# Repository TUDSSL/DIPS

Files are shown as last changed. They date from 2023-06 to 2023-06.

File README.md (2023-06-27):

# DIPS
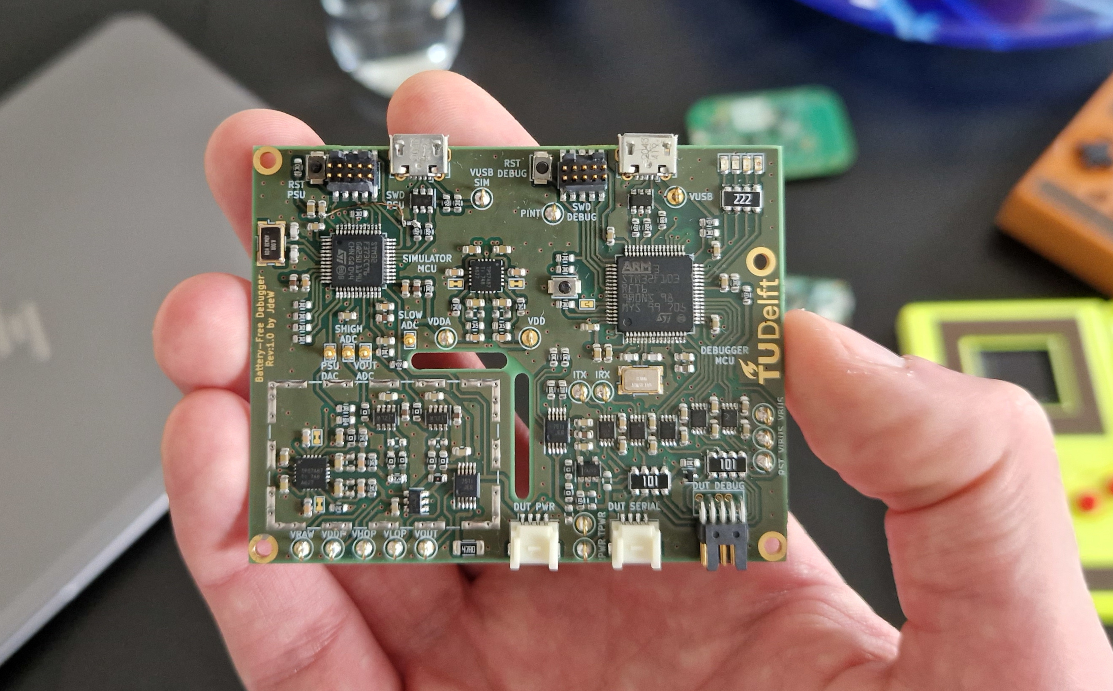
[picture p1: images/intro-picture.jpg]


This is the official public repository for **DIPS**: **D**ebugger for **I**ntermittently-**P**owered **S**ystems. The repository consists of all components that make DIPS:
- [Hardware](https://github.com/TUDSSL/DIPS/tree/master/hardware)
- [Debugger Firmware](https://github.com/TUDSSL/DIPS/tree/master/int-debugger-firmware)
- [Emulator Firmware](https://github.com/TUDSSL/DIPS/tree/master/int-debugger-emulator)
- [Emulator Host (GUI)](https://github.com/TUDSSL/DIPS/tree/master/int-debugger-emulator-host)
- [DIPS Console](https://github.com/TUDSSL/DIPS/tree/master/int-debugger-console)

## Project Overview
### Rationale
Intermittently-Powered or Battery-Free systems are low-powered embedded systems that experience frequent power failures. In recent years intermittently-powered systems have been explored excessively by the research community, but there was no good way of debugging these systems. DIPS aims to address this challenge. 

### Debugging Intermittently-Powered Systems
Common debuggers, like the [J-link](https://www.segger.com/products/debug-probes/j-link/), are perfect for debugging continuously-powered systems but will lose connection on a power failure when debugging intermittently-powered systems, making it useless for debugging battery-free systems. On top of that, intermittently-powered systems come with their own set of challenges by introducing new architectures like checkpointing. DIPS allows for continuous debugging despite power failures by reconnecting automatically and restoring the debugging state (Breakpoints) to the device under test. Scripts supplement the functionality of DIPS, allowing for automated tests of memory and peripheral consistency.

### Features:
DIPS integrates a fully featured emulator with close integration with an onboard hardware debugger. It can power devices under test through various modes and features current measurement capability. A key feature is the ability to pause emulation during debugger interaction, such as breakpoints. The emulator supports the following modes:
- Constant Voltage
- Sawtooth
- Square
- Triangle
- Virtual Buck-Boost (Allows for replaying energy harvesting traces to the device under test)
- Passive mode (Only takes over powering the device when prompted during debugging, requires passive debugging mode **mon passive_mode enable**)

The hardware debugger supports, through the associated console application, supports the following features:

- **energy_guards** energy-neutral code sections  where the emulator pauses
- **energy_breakpoints** that only trigger if the voltage is lower than the specified threshold
- **dips_mem_check** memory state consistency verification script, configured in **dips_testing.json**
- **dips_peripheral_check** peripheral state consistency verification script, configured in **dips_testing.json**
- Printing (**DIPS_PRINTF**), asserts (**DIPS_ASSERT**) and manually attaching (**DIPS_ATTACH**) through a simple C interface
- Passive operation (**wait_connect**) where the debugger only connects when prompted through a pin. 

### Hardware
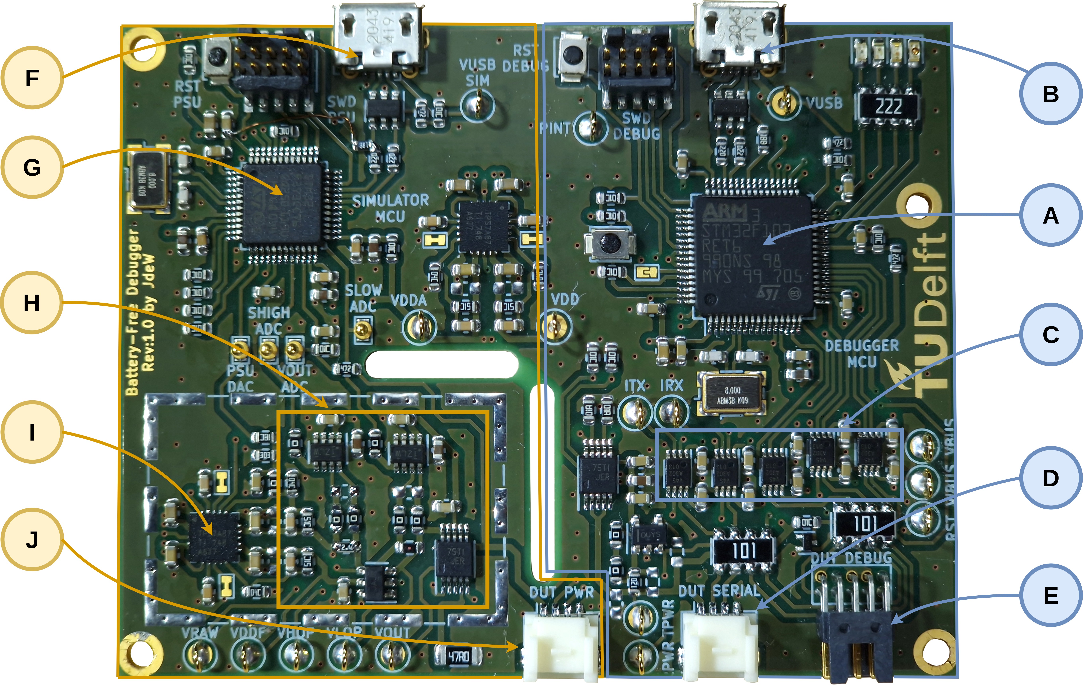
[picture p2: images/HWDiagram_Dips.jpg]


#### Hardware Debugger
The hardware design of the debugger centers around a STM32F103RET MCU (A) and is based on the [Black Magic Debug Probe](https://github.com/blackmagic-debug/blackmagic). It is able to communicate with the energy emulator through SPI. The MCU interfaces with the DUT through SWD/JTAG or SBW (E), I/O interrupt pins and acts as a UART-USB bridge (D). To translate the signals to the DUT voltage, first, the DUT voltage is buffered using a low input bias current buffer amplifier OPA192. Next, all the interfaces with the DUT are level shifted by level translators (C) using the buffered DUT
voltage. The debugger connects to the PC with USB (B). 

#### Energy Emulator 
Central to the energy emulator is the low-noise TPS7A87 (I) linear regulator. The regulator generates the adjustable supply rail to the DUT (J). Power consumption by the DUT is measured by two INA186 current sense amplifiers (H). The first amplifier with a 5.6 Ω sense resistor measures large currents without imposing a high burden voltage. The second amplifier with a 1000 Ω sense resistor measures low currents and is able to be bypassed at large currents preventing high burden voltages. Two analog switches allow for quickly disabling the output and discharging the output through a 47 Ω resistor. The emulator is controlled by a STM32F373 MCU (G). With its on-board DAC DIPS is able to adjust the linear regulator and samples the output voltage and the output of the current sense amplifiers (each using one of its dedicated on-board Sigma Delta ADCs). The energy emulator connects to the PC with USB (F)

#### Design files
In the **hardware** folder both the KICAD design files are provided together with a PDF schematic and gerbers.

## Getting Started
This repository has all information to build your own DIPS. Below we describe building and executing the complete repository of DIPS, including hardware, debugger software, emulator software and both emulator and console applications.

### Building the Debugger Firmware
The hardware debugger firmware is based on the [Black Magic Probe](https://github.com/blackmagic-debug/blackmagic) and can be found in the [/int-debugger-firmware](https://github.com/TUDSSL/DIPS/tree/master/int-debugger-firmware) folder

#### Build Process
After cloning the repository one can compile the firmware in two ways, first is by running it as a [PlatformIO](https://platformio.org/) project or by building it from scratch using the provided cmake files running the following section:

```
$ cd int-debugger-firmware
$ pio run
```

After building, you can upload the firmware to the MCU using your favourite flashing method whilst powering the platform using USB.

#### Last Tested Software Versions
This software was build successfully with these software versions:

- CMake version 3.26.3 
- arm-none-eabi-gcc version 13.1.0 
- arm-none-eabi-newlib version 4.3.0.20230120
- arm-none-eabi-binutils version 2.40 
- PlatformIO version 6.1.7

### The Emulator Firmware
The emulator firmware is located in the [/int-debugger-emulator](https://github.com/TUDSSL/DIPS/tree/master/int-debugger-emulator) folder

#### Build Process
After cloning the repository the emulator can be compiled and build by running the enclosed cmake commands:

```
$ cd int-debugger-emulator
$ mkdir build
$ cd build
$ cmake ..
$ make
```

After building, you can upload the firmware to the MCU using your favourite flashing method whilst powering the platform using USB.

#### Note on the Emulator Firmware
The firmware is based upon the [FreeRTOS](https://www.freertos.org/) framework, allowing real-time switching of tasks required for the emulator.

#### Last Tested Software Versions
This software was build successfully with these software versions:

- CMake version 3.26.3 
- arm-none-eabi-gcc version 13.1.0 
- arm-none-eabi-newlib version 4.3.0.20230120
- arm-none-eabi-binutils version 2.40
- Protobuf version 21.12

### Building the Emulator Host Software
The next part of software runs on the host PC and is used for communicating with the hardware emulator. The sofware can be found in the [/int-debugger-emulator-host](https://github.com/TUDSSL/DIPS/tree/master/int-debugger-emulator-host) folder.

#### Build Process
After cloning the repository the emulator host application can be compiled and build by running the following commands:

```
$ cd int-debugger-emulator-host
$ cmake .
$ make
```

#### Last Tested Software Versions
This software was build successfully with these software versions:

- [QT](https://www.qt.io/) version 5.15.9
- [HighFive](https://github.com/BlueBrain/HighFive) commit 00dad7172c
- Protobuf version 21.12
- HDF5 version 1.14.1

### The DIPS Console Software
The next part of software also runs on the host PC and is used as a GDB wrapper, allowing the added features of DIPS. The sofware can be found in the [/int-debugger-console](https://github.com/TUDSSL/DIPS/tree/master/int-debugger-console) folder.

#### Setup
Since the DIPS console is a python executable, there is no need for compilation. Install the python libraries mentioned in the `requirements.txt` file and you should be good to go.

#### Last Tested Software Versions
This software was build successfully with these software versions:

- Python version 3.11.3
- Python-pyGDBmi version 0.11.0.0
- Python-pyserial version 3.5
- Python-prompt_toolkit version 3.0.38 
- Python-cmsis_svd version 0.4

#### Execute DIPS Console Application
The DIPS console application can be started by calling the `python3 main.py`, if you have an elf-file binary, you can load this by adding this as extra parameter `python3 main.py firmware.elf`. Other GDB parameters and queries from the command line are avaliable as well.

##### Connecting to DIPS
If you have your DIPS connected over USB you can connect to the hardware by running the `connect` command. The console will automatically search for a DIPS serial connection, establish this connection and connect to the attached device under test. Now one can start debugging intermittenlty-powered systems with DIPS, just like debugging regular powered embedded systems. Manual connection to DIPS is also possible by running the following sequence:

```
(gdb) tar ext /dev/ttyACM0
(gdb) mon s
(gdb) attach 1
```

##### Sample session
After connecting to the DIPS and the device under test, regular arm-none-eabi-gdb commands are availble for use:

```
> python3 main.py example.elf
...<GDB Copyright message>
(gdb) connect
Remote debugging using /dev/ttyACM0
Target voltage: 3.00V
Available Targets:
No. Att Driver
 1      STM32F40x M3/M4
Attaching to program: <code_folder>/example.elf, Remote target
0x800007c in main ()
(gdb) load
Loading section .text, size 0x5868 lma 0x8000000
Loading section .data, size 0x9e0 lma 0x8005868
Loading section .rodata, size 0x254 lma 0x8006248
Start address 0x800007c, load size 25756
Transfer rate: 31 KB/sec, 919 bytes/write.
(gdb) b main
(gdb) c
Breakpoint 1 at 0x80000e8: file <code_folder>/main.c, line 20.
(gdb)
```
## How to Cite This Work

The results of this project have been published in a peer-reviewed academic publication (from which all technical figures in this file originate). Details of the publication are as follows.

* **Authors and the project team:** [Jasper de Winkel](https://www.jasperdewinkel.com/), [Tom Hoefnagel](https://www.linkedin.com/in/tobrec), [Boris Blokland](https://www.linkedin.com/in/boris-blokland-2a0b22138/), [Przemysław Pawełczak](https://www.pawelczak.net/)
* **Publication title:** _DIPS: Debug Intermittently-Powered Systems Like Any Embedded System_
* **Pulication venue:** [Proceedings of ACM SenSys 2022](http://sensys.acm.org/2022/)
* [**Link to publication**](https://doi.org/10.1145/3560905.3568543)

To cite this publication please use the following BiBTeX entry.

```
@inproceedings{dewinkel:sensys:2022:dips,
 author = {de Winkel, Jasper and Hoefnagel, Tom and Blokland, Boris and Pawe\l{}czak, Przemys\l{}aw},
 title = {{DIPS}: Debug Intermittently-Powered Systems Like Any Embedded System},
 booktitle = {Proc. SenSys},
 year = {2022},
 address = {Boston, MA, USA},
 date = nov # " 6--9",
 publisher = {ACM},
 url = {https://doi.org/10.1145/3560905.3568543}
}
```

## Acknowledgments

This research project was supported by [Netherlands Organisation for Scientific Research](https://www.nwo.nl/en), partly funded by the [Dutch Ministry of Economic Affairs and Climate Policy](https://www.government.nl/ministries/ministry-of-economic-affairs-and-climate-policy), through [TTW Perspective program ZERO (P15-01)](https://www.nwo.nl/en/researchprogrammes/perspectief/previous-awards/zero-towards-energy-autonomous-systems-iot) within Project P1.

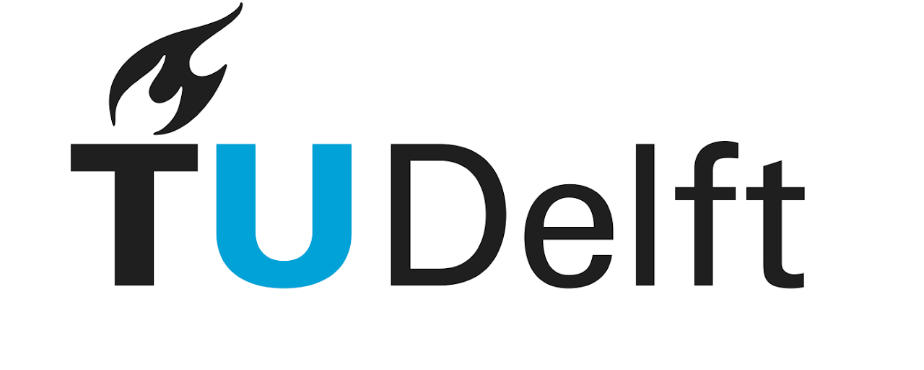
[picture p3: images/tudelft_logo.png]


## Copyright

Copyright (C) 2022 TU Delft Embedded Systems Group/Sustainable Systems Laboratory.

MIT Licence or otherwise specified. See [license](https://github.com/TUDSSL/ENGAGE/blob/master/LICENSE) file for details.

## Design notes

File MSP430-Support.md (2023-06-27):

# DIPS Support for MSP430
In this document we outline the current development status of supporting [MSP430 MCUs](https://www.ti.com/microcontrollers-mcus-processors/microcontrollers/msp430-microcontrollers/overview.html) with DIPS. As at the base of DIPS' debugging features is [Black Magic software](https://github.com/blackmagic-debug), where MSP430 support is not provided per default, thus needs to be manually added. DIPS does support the [MSP432 MCU](https://en.wikipedia.org/wiki/TI_MSP432) series (as this is an ARM core), and generic support is provided for Cortex-M0/M3 and M4. Any chip with these ARM cores should be debuggable using DIPS, even though they are not directly supported. Additional features, such as programming, would require device-specific implementation in DIPS/Black Magic as these implementations vary per chip unfortunately.

First, we outline the interface and how the DIPS debugger connects to the MSP430 under test. Second, we further describe the software support.

_Important note_: Since the MSP430 debug feature is under active development, this document will be updated as further support is added.

## Interface
For MSP430 devices the Spy-by-wire (SBW) interface is commonly used within intermittent computing platforms. This is a serialized JTAG interface custom to the Texas Instruments (TI) MSP430 platform reducing the number of required pins during debugging. 

On development boards of the MSP430, such as [MSP-EXP430FR5994](https://www.ti.com/product/MSP430FR5994) and [MSP-EXP430FR5969](https://www.ti.com/product/MSP430FR5969), communication with the onboard debugger occurs through SBW. As this is the most common option for debugging (and intermittent systems are most often bound by space restriction), we chose to support MSP430 through SBW. Using an adapter cable, we can directly connect MSP430 devices to DIPS. The connections of this cable are listed in the figure below. We note that these connections are in addition to a possible connection to the emulator through the emulator output connector on DIPS.

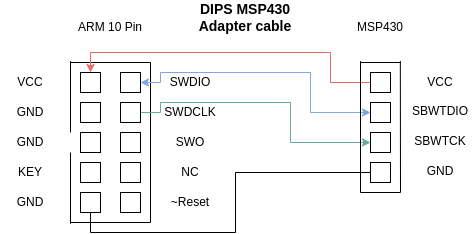
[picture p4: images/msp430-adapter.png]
DIPS MSP430 Adapter Cable


Since DIPS's architecture includes level shifters on the debugger output, SBW signals generated from the debugger are shifted to the voltage sensed on the VCC pin of the MSP430, fulfilling the required signal level constraints. Therefore we do not foresee any issues regarding the hardware capability of DIPS debugging MSP430 since the level shifters of DIPS are capable of 60 Mbps transfer at 1.5 V, far exceeding the connection requirements. The MCU controlling the debugging within DIPS is also far more capable than the chips serving as integrated debuggers in the TI development kits. Hence the timing requirements of DIPS should be met without issue.

## Spy-by-Wire Protocol
TI provides a user's guide for [programming with the JTAG/SBW interface](https://www.ti.com/lit/ug/slau320aj/slau320aj.pdf). Our implementation is based on the protocol description in this document. Please note however that this document does not provide information about setting breakpoints and watchpoints. This unfortunately requires reverse engineering of the open source [debugger code](https://www.ti.com/tool/MSPDS) from TI.

For the record, the figure below (taken from [TI Users guide (Figure 2-10)](https://www.ti.com/lit/ug/slau320aj/slau320aj.pdf)) shows a detailed diagram of how SBW operates.

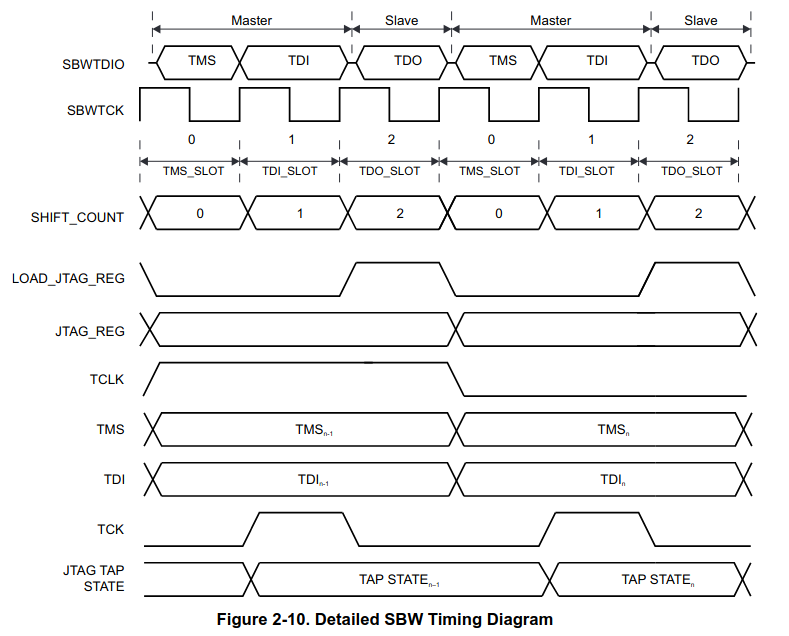
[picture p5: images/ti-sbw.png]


The traditional JTAG signals TMS, TDI and TDO are multiplexed on a single I/O line. This introduces further timing requirements in order to keep alignment with the MSP430 under test. As of now the SBW communication primitives are implemented and further features are developed, such as CPU control and reading/writing from/to memory.

## DIPS Software Support

| Command | Status |
| --- | --- |
| Attach/detatch | Yes |
| Register reads/writes | Yes | 
| Reset | Pending | 
| Halt/resume | Yes | 
| Breakpoints | Yes | 
| Watchpoints | Pending | 
| Energy breakpoints | Yes | 
| Energy guards | Yes | 

### Attaching

DIPS queries the JTAG and SWD interfaces to connect with devices under test. When a device responds, the target ID is retrieved together with vendor-specific IDs (when possible) to determine FLASH/RAM sizes etc. Then the correct target driver is loaded.

We extend this interface with another query to find MSP430 devices on the SBW bus. When an MSP430 device responds to the query, the internal commands (e.g. reg read/write/ breakpoints) are switched to custom MSP430 compatible ones, retargeting the debugger from ARM to MSP430. 

Below a screenshot is shown of DIPS attaching to an MSP430 from the console perspective. In addition, some of the underlying SBW queries between DIPS and the MSP430 are shown to fetch the COREID and JTAGID to identify the chip.

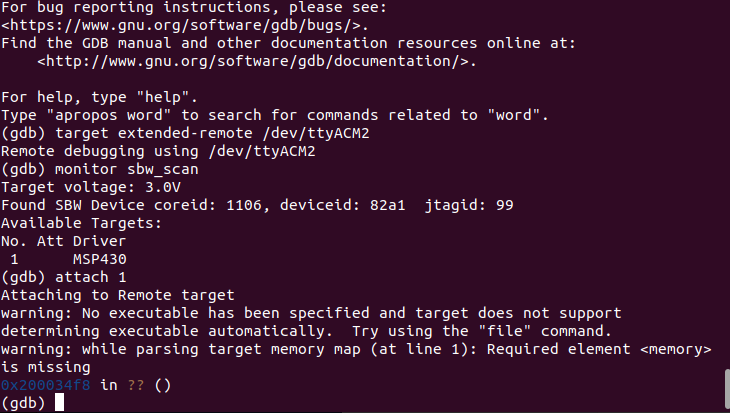
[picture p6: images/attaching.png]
DIPS Attach in console

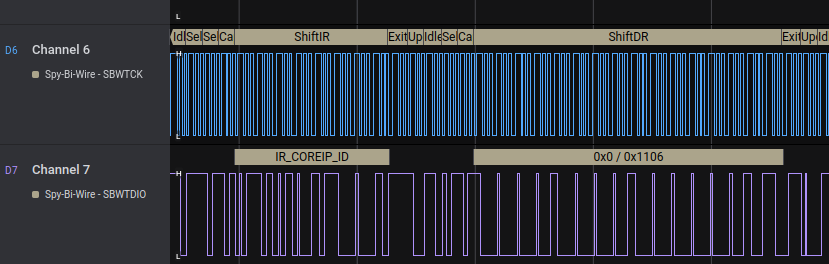
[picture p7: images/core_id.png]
Trace COREID read

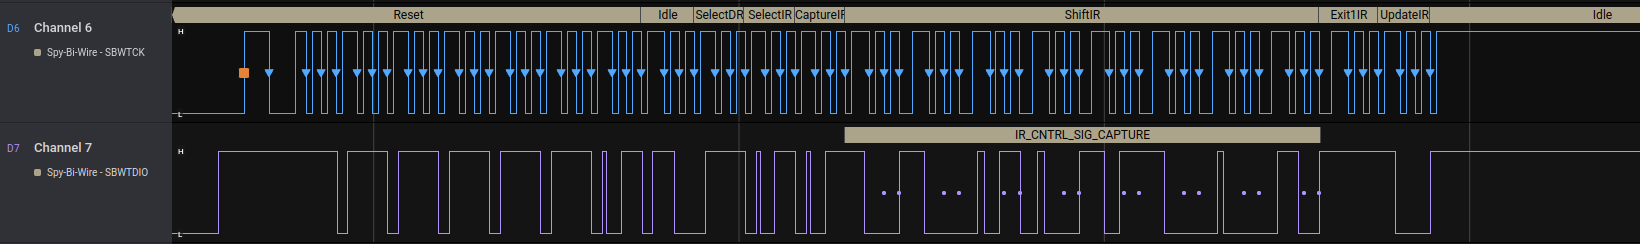
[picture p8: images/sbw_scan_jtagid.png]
Trace JTAGID


## Debugging MSP430 with DIPS

Due to the different instruction set of the MSP430, TI has its own fork of the GCC suite, named MSP430-GCC. TI's development environment for MSP430 is named Code Composer Studio (CCS), an Eclipse-based IDE. Per default this IDE uses TI's proprietary debugging engine connecting to the MSP-FET debugger. When debugging using open source tools, a common method is to use msp430-gdb and a translation library like MSPDebug to act as a GDB server converting gdb client commands to the TI interface that controls the MSP-FET.

We propose a setup similar to the ARM debugging scenario where DIPS directly acts as the GDB Server and then internally converts messages to SBW commands. We note that even in the case of using CCS open-source suite, debugging with GDB can be configured. An overview of these options is shown in the figure below.

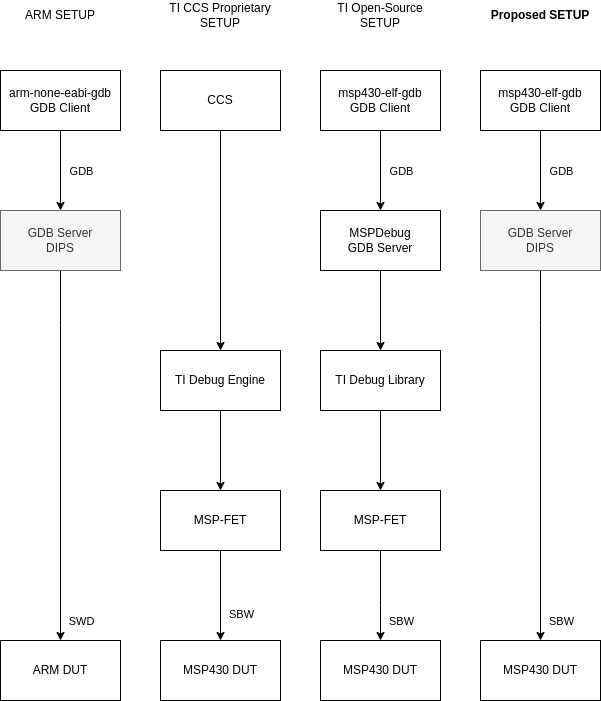
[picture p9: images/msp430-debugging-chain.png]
DIPS MSP430 Debugging Architecture


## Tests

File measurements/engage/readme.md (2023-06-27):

For this example we used an unmodified version of the Battery-free Game Boy source code from (https://github.com/TUDSSL/ENGAGE)

From the ENGAGE folder:

```
cd software/build/
cmake ../
make -j12
```

The emulator binary was then flashed to ENGAGE and a game was loaded prior to starting the measurements. Logs and settings of the ENGAGE measurements can be found in their respective folders.

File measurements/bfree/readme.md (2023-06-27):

In order to run the BFree measurements, BFree has to be modified to allow access to SWD. Per default the SWD pins are used as GPIO, in both Micropython as the bootloader. 

Both a modified version of BFree and the bootloader is provided in the software folder. Logs and settings of the BFree measurements can be found in their respective folders.

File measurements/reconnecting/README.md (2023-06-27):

# Reconnecting Measurement Artefacts
Here you can find the raw measurements preformed for section 5.1 - Figure 4. 
Using the [Saleae Logic Pro 8](http://downloads.saleae.com/specs/Logic+Pro+8+Product+Fact+Sheet.pdf)

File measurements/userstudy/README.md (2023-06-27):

# Userstudy Artefacts

Create the plot using the plotter.py. 
Please note in study2 are unfinished results. These results can be ignored as this was due to a bug in the suvey environment.

## Requirements
Pyton 3
Numpy
Matplotlib

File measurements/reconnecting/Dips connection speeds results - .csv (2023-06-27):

MCU | NRF52 |  | ATMEL |  | Apollo 3 |  | STM32 |  | NXP
#1 | 297.9 | 57.8 | 314 | 87.4 | 280 | 105 | 302.8 | 77.5 | 304.3 | 152.2
#2 | 267.2 | 91.12 | 317 | 79.8 | 303.6 | 102.5 | 340.4 | 87.9 | 306.1 | 115
#3 | 296 | 106.1 | 287.6 | 69.75 | 431.4 | 123.9 | 302.1 | 95.6 | 271.6 | 98.7
#4 | 288.6 | 65 | 327.4 | 66.52 | 318.4 | 87.8 | 295.6 | 111.4 | 277.5 | 66.8
#5 | 296.3 | 119.1 | 328 | 93.9 | 337.1 | 94.8 | 320.7 | 67.4 | 333.2 | 142
#6 | 285.1 | 68.6 | 438.4 | 45 | 339.9 | 105 | 331.8 | 100.7 | 308.3 | 139.5
#7 | 341.3 | 29 | 281.8 | 93.1 | 313.5 | 57 | 327.9 | 62.1 | 341.7 | 91.7
#8 | 345.2 | 73 | 304.9 | 72.2 | 332.9 | 81 | 258.3 | 33 | 326.6 | 65.6
#9 | 353.1 | 52 | 308.6 | 60.8 | 351.1 | 80.9 | 351.8 | 22.5 | 340.2 | 91.7
#10 | 340.4 | 65 | 338.9 | 89.2 | 302.8 | 118.3 | 354.9 | 23.4 | 286.1 | 94.4
Average | 311.11 | 72.672 | 324.66 | 75.767 | 331.07 | 95.62 | 318.63 | 68.15 | 309.56 | 105.76

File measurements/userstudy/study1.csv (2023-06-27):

id. Response ID | submitdate. Date submitted | lastpage. Last page | startlanguage. Start language | seed. Seed | Introduction. Ready? | IntroductionB. Ready? | A000. Enter the password to continue (Ask US after Playing with the debugger for 15 minutes) | BugA10. Bug 1: This first bug has to do with how the Fibonacci is defined here. This Fibonacci function uses n+1 and n+2 what leads to a diverging function as the base case is never reached. The solution is to replace n+1 by n-1 and n+2 by n-2. Did you find the bug? | BugA11[SQ001]. How difficult was it to find the bug? [Debugger] | BugA12. Did you find the bug using the debugger? (Otherwise please specify) | BugA12[other]. Did you find the bug using the debugger? (Otherwise please specify) [Other] | BugA13[SQ001]. Did the debugger help in finding the bug? [Debugger] | BugA20. Bug 2: The second bug can be found in the matrix multiply function (tasks/matrix.cpp). Here the sum variable is cleared only every row iteration, while it should be cleared every column as well. The solution is to move the int sum =0 to within the (j &lt; 6) while loop. Did you find the bug? | BugA21[SQ001]. How difficult was it to find the bug? [Debugger] | BugA22. Did you find the bug using the debugger? (Otherwise please specify) | BugA22[other]. Did you find the bug using the debugger? (Otherwise please specify) [Other] | BugA23[SQ001]. Did the debugger help in finding the bug? [Debugger] | BugA30. Bug 3: The last bug is a famous intermittent bug. The UART peripheral is only initialized after the restoration of the memory after a power failure. This means whenever a power failure occurs and case 2 or 3 is true, this UART initialization is skipped. One can solve this by moving the UART setup to someplace before the switch-case. Did you find the bug? | BugA31[SQ001]. How difficult was it to find the bug? [Debugger] | BugA32. Did you find the bug using the debugger? (Otherwise please specify) | BugA32[other]. Did you find the bug using the debugger? (Otherwise please specify) [Other] | BugA33[SQ001]. Did the debugger help in finding the bug? [Debugger] | B000. Enter the password to continue (Ask US after Playing with the debugger for 15 minutes) | BugB10. Bug 1: The snippet shows the first bug of the WISP system. The blink_COUNTER variable is misspelt, this creates an infinite loop as blink_C0UNTER is never updated. The solution is to replace the 0 with O. Did you find the bug? | BugB11[SQ001]. How difficult was it to find the bug? [Debugger] | BugB12. Did you find the bug using the debugger? (Otherwise please specify) | BugB12[other]. Did you find the bug using the debugger? (Otherwise please specify) [Other] | BugB13[SQ001]. Did the debugger help in finding the bug? [Debugger] | BugB20. Bug 2: The second bug has to do with the result variable, which is never pointed to any memory. This can be solved by allocating the memory using malloc or by initializing the array at the beginning. Did you find the bug? | BugB21[SQ001]. How difficult was it to find the bug? [Debugger] | BugB22. Did you find the bug using the debugger? (Otherwise please specify) | BugB22[other]. Did you find the bug using the debugger? (Otherwise please specify) [Other] | BugB23[SQ001]. Did the debugger help in finding the bug? [Debugger] | BugB30. Bug 3: The snippet shows bug 3. The initialization of the ADC (setup_adc()) happens after the restoration, although, if restoring after a power failure case 2 or 3 is true, the setup is not executed. This is a very common mistake in Intermittent Computing Systems. The solution is to move the setup_adc() function above the restoration (switch case) Did you find the bug? | BugB31[SQ001]. How difficult was it to find the bug? [Debugger] | BugB32. Did you find the bug using the debugger? (Otherwise please specify) | BugB32[other]. Did you find the bug using the debugger? (Otherwise please specify) [Other] | BugB33[SQ001]. Did the debugger help in finding the bug? [Debugger] | C1[SQ001]. If you would work on the code for battery-free device: would you use this debugger system? [System A] | C1[SQ002]. If you would work on the code for battery-free device: would you use this debugger system? [System B] | C2[SQ001]. Was the debugging experience with each debugging system close to the one you have? [System A] | C2[SQ002]. Was the debugging experience with each debugging system close to the one you have? [System B] | C3[SQ001]. How intuitive to use was each of the debugging systems? [System A] | C3[SQ002]. How intuitive to use was each of the debugging systems? [System B] | C4[SQ001]. How easy to use was each of the debugging systems? [System A] | C4[SQ002]. How easy to use was each of the debugging systems? [System B] | C5. What are the positive aspects about System B? | C6. What are the negative aspects about System B? | C7. What are the positive aspects about System A? | C8. What are the negative aspects about System A? | A12. What is your age? | A1. You are: | A2. With which programming language you are most comfortable with? | A2[other]. With which programming language you are most comfortable with? [Other] | A3. Have you ever used an Integrated Development Environment (IDE) when developing your applications? | A4. Do you prefer to develop your applications using an Integrated Development Environment (IDE)? | A5[SQ001]. How do you assess your embedded systems programming skills? [Expertise] | A6. Have you ever used hardware-based debuggers for your embedded project (such as Seggers J-link - see photo below)? | A7. Have you ever used debugging techniques such as breakpoints, watchpoints, memory views, peripheral views, etc. while debugging an embedded system?
4 | 1980-01-01 00:00:00 | 6 | en | 1653865737 | Yes | Yes | apple | No |  |  |  |  | No |  |  |  |  | No |  |  |  |  | pear | No |  |  |  |  | No |  |  |  |  | No |  |  |  |  | Yes | No | Similar to what I am used to | Different from what I am used to | Intuitive | Non-intuitive | Neither easy nor difficult | Neither easy nor difficult | I think this system might be to the liking of those who prefer terminal over GUI. | Not very intuitive and probably unlike what most users are used to. | Very similar to most debuggers. People will have an easier time learning how to use this one. | Can't think of any. | 23 | Female | Python |  | Yes | Yes | Some experience | No | Yes
5 | 1980-01-01 00:00:00 | 6 | en | 219549667 | Yes | Yes | apple | No |  |  |  |  | No |  |  |  |  | No |  |  |  |  | pear | No |  |  |  |  | No |  |  |  |  | No |  |  |  |  | No | Yes | Similar to what I am used to | Similar to what I am used to | Intuitive | Non-intuitive | Somewhat difficult | Somewhat difficult | It allows you to set breakpoints in the code. Also, the terminal debugger may allow for automated scripts, and result reporting. | Having to reflash after setting a new breakpoint in the code. | Being able to use the GUI debugging buttons (step over, step out, etc.) which is what I'm used to. | The program got a segmentation fault at the start, and the debugger output could not point me in the right direction. | 24 | Male | C/C++ |  | Yes | Yes | Little experience | Yes | Yes
6 | 1980-01-01 00:00:00 | 6 | en | 1705827728 | Yes | Yes | apple | Yes | Neither easy nor difficult | Yes |  | Yes | No |  |  |  |  | No |  |  |  |  | pear | No |  |  |  |  | No |  |  |  |  | No |  |  |  |  | Yes | Yes | Different from what I am used to | Different from what I am used to | Intuitive | Non-intuitive | Neither easy nor difficult | Neither easy nor difficult | terminal driven (less switching once learning it) | terminal driven (steep learning curve) | tightly integrated to IDE | switching between tabs for building/loading | 34 | Male | Python |  | Yes | Yes | A lot of experience | Yes | Yes
7 | 1980-01-01 00:00:00 | 6 | en | 15004810 | Yes | Yes | apple | Yes | Neither easy nor difficult | Yes |  | Some What | No |  |  |  |  | No |  |  |  |  | pear | No |  |  |  |  | No |  |  |  |  | No |  |  |  |  | Yes | Yes | Similar to what I am used to | Different from what I am used to | Neither intuitive nor non-intuitive | Non-intuitive | Easy | Somewhat difficult | It shows the voltage stored in the capacitor if you're careful with the temporary stored energy such that it has not too little or too much voltage. | I was struggling with errors that occur when using debug commands, therefore rendering me to be unable to even start finding the bugs. | It was easy and intuitive to work with. | The green restart button doesn't seem to function correctly. Had to go through some pop-up windows. | 23 | Male | C/C++ |  | Yes | Yes | A lot of experience | Yes | Yes
8 | 1980-01-01 00:00:00 | 6 | en | 1264031530 | Yes | Yes | apple | Yes | Neither easy nor difficult | Yes |  | Yes | No |  |  |  |  | No |  |  |  |  | pear | No |  |  |  |  | No |  |  |  |  | No |  |  |  |  | Yes | No | Similar to what I am used to | Similar to what I am used to | Absolutely intuitive | Absolutely intuitive | Easy | Somewhat difficult | programmer friendly | need proper documentation before we can work on it. | Easy to use. similar to other debuggers | none | 26 | Male | Python |  | Yes | Yes | Some experience | Yes | Yes
9 | 1980-01-01 00:00:00 | 6 | en | 1750218359 | Yes | Yes | apple | Yes | Easy | Yes |  | Yes | No |  |  |  |  | No |  |  |  |  | pear | No |  |  |  |  | No |  |  |  |  | No |  |  |  |  | Yes | No | Similar to what I am used to | Similar to what I am used to | Intuitive | Non-intuitive | Easy | Somewhat difficult | I am used to GDB debugger for C/C++ debugging, so it was bit similiar to that. | Adding breakpoints in the code and compiling again is cumbersome to do everytime. 'wait, int, break' commands is not so initutive. | Compiling once is enough to debug in the hardware. Reflashing is not required. Breakpoints and continuing into the code is more of GUI based and intuituve than browsing through the code. | Had a bit of learning or getting used time, but once got a hang of it, it was slick and easy. | 27 | Male | C/C++ |  | Yes | Yes | A lot of experience | No | Yes
10 | 1980-01-01 00:00:00 | 6 | en | 1441815904 | Yes | Yes | apple | Yes | Neither easy nor difficult | Yes |  | Yes | No |  |  |  |  | No |  |  |  |  | pear | No |  |  |  |  | No |  |  |  |  | No |  |  |  |  | No | No | Very different from what I am used to | Different from what I am used to | Intuitive | Non-intuitive | Somewhat difficult | Very difficult | None, I still have no clue what it is. | Debugger does not work as described. No resolving of symbols. | Nice to set breakpoints in editor. | Still don't understand how to use it. | 44 | Male | C/C++ |  | Yes | No | A lot of experience | Yes | Yes
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

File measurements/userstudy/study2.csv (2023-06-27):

Response ID,Date submitted,Last page,Start language,Seed,Ready?,Ready?,Enter the password to continue (Ask US after Playing with the debugger for 15 minutes),Bug 1:     This first bug has to do with how the Fibonacci is defined here. This Fibonacci function uses n+1 and n+2 what leads to a diverging function as the base case is never reached. The solution is to replace n+1 by n-1 and n+2 by n-2.       Did you find the bug?    ,How difficult was it to find the bug? [Debugger],Did you find the bug using the debugger? (Otherwise please specify),Did you find the bug using the debugger? (Otherwise please specify) [Other],Did the debugger help in finding the bug? [Debugger],"Bug 2:     The second bug can be found in the matrix multiply function (tasks/matrix.cpp). Here the sum variable is cleared only every row iteration, while it should be cleared every column as well. The solution is to move the int sum =0 to within the (j &lt; 6) while loop.       Did you find the bug?    ",How difficult was it to find the bug? [Debugger],Did you find the bug using the debugger? (Otherwise please specify),Did you find the bug using the debugger? (Otherwise please specify) [Other],Did the debugger help in finding the bug? [Debugger],"Bug 3:     The last bug is a famous intermittent bug. The UART peripheral is only initialized after the restoration of the memory after a power failure. This means whenever a power failure occurs and case 2 or 3 is true, this UART initialization is skipped. One can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
1,,2,en,704032007,Yes,Yes,,N/A,,,,,N/A,,,,,N/A,,,,,,N/A,,,,,N/A,,,,,N/A,,,,,,,,,,,,,,,,,,N/A,,,N/A,N/A,,N/A,N/A,N/A,N/A,N/A,N/A,,N/A,N/A,,,,,,,,,,,,,,,,,,,,,,,,,,,,,,,,,,,,,,,,,,,,,,,,,,,,,,,,
2,,2,en,54428909,Yes,Yes,,N/A,,,,,N/A,,,,,N/A,,,,,,N/A,,,,,N/A,,,,,N/A,,,,,,,,,,,,,,,,,,N/A,,,N/A,N/A,,N/A,N/A,N/A,N/A,N/A,N/A,,N/A,N/A,,,,,,,,,,,,,,,,,,,,,,,,,,,,,,,,,,,,,,,,,,,,,,,,,,,,,,,,
3,,2,en,948952438,Yes,Yes,pear,N/A,,,,,N/A,,,,,N/A,,,,,,N/A,,,,,N/A,,,,,N/A,,,,,,,,,,,,,,,,,,N/A,,,N/A,N/A,,N/A,N/A,N/A,N/A,N/A,N/A,,N/A,N/A,,,,,,,,,,,,,,,,,,,,,,,,,,,,,,,,,,,,,,,,,,,,,,,,,,,,,,,,
4,2022-09-26 12:23:05,6,en,1899562523,Yes,Yes,apple,Yes,Somewhat difficult,Yes,,A little,Yes,Very difficult,Other,the logic of summation,No,No,,,,,pear,No,,,,,Yes,Somewhat difficult,Other,logic and experience with c,No,No,,,,,Yes,No,Similar to what I am used to,Similar to what I am used to,Intuitive,Non-intuitive,Somewhat difficult,Very difficult,"With some more experience, i could imagine that you have more control over the way this debugger works.",it is counterintuitive. the need for flushing especially.,intuitive and commonly used,a bit of a black box what is actually happening,28,Male,Python,,Yes,No,Little experience,No,Yes,Yes,Yes,Yes,No,,No,No,Somewhat difficult,,,,,,,,,,,,,,,,,,,,,,,,,,,,,,,,,,,,,,,,,,,,,,,,,,,,,,,
5,,2,en,241951371,Yes,Yes,,N/A,,,,,N/A,,,,,N/A,,,,,,N/A,,,,,N/A,,,,,N/A,,,,,,,,,,,,,,,,,,N/A,,,N/A,N/A,,N/A,N/A,N/A,N/A,N/A,N/A,,N/A,N/A,,,,,,,,,,,,,,,,,,,,,,,,,,,,,,,,,,,,,,,,,,,,,,,,,,,,,,,,
6,,3,en,511071445,Yes,Yes,apple,Yes,Easy,Yes,,Yes,Yes,Neither easy nor difficult,Yes,,Yes,No,,,,,,N/A,,,,,N/A,,,,,N/A,,,,,,,,,,,,,,,,,,N/A,,,N/A,N/A,,N/A,N/A,N/A,N/A,N/A,N/A,,N/A,N/A,,,,,,,,,,,,,,,,,,,,,,,,,,,,,,,,,,,,,,,,,,,,,,,,,,,,,,,,
7,2022-09-26 14:27:16,6,en,1750703097,Yes,Yes,apple,Yes,Easy,Yes,,Yes,Yes,Neither easy nor difficult,Yes,,Yes,No,,,,,pear,Yes,Very difficult,Yes,,A little,No,,,,,No,,,,,Yes,No,Similar to what I am used to,Very different from what I am used to,Absolutely intuitive,Absolutely non-intuitive,Very easy,Very difficult,I suppose having the breakpoints directly in the source files makes it easier to have the same breakpoints on multiple machines,"- Recompiling after every change in breakpoints is very cumbersome
- Being ""CLI only"" makes it hard to make intuitive sense of what is happening
-  I wasn't able to define multiple breakpoints","- Easy to use and understand
- Changing breakpoint locations on the go is helpful
- Stepping through code is very useful
- Having all the values of variables in the context in one overview is nice",Compared to system B I cannot think of any,27,Male,C/C++,,Yes,Yes,A lot of experience,Yes,Yes,Yes,Yes,Yes,Yes,,No,No,Somewhat difficult,,,,,,,,,,,,,,,,,,,,,,,,,,,,,,,,,,,,,,,,,,,,,,,,,,,,,,,
8,,3,en,647297054,Yes,Yes,apple,No,,,,,No,,,,,No,,,,,,N/A,,,,,N/A,,,,,N/A,,,,,,,,,,,,,,,,,,N/A,,,N/A,N/A,,N/A,N/A,N/A,N/A,N/A,N/A,,N/A,N/A,,,,,,,,,,,,,,,,,,,,,,,,,,,,,,,,,,,,,,,,,,,,,,,,,,,,,,,,
9,,2,en,694785966,Yes,Yes,,N/A,,,,,N/A,,,,,N/A,,,,,,N/A,,,,,N/A,,,,,N/A,,,,,,,,,,,,,,,,,,N/A,,,N/A,N/A,,N/A,N/A,N/A,N/A,N/A,N/A,,N/A,N/A,,,,,,,,,,,,,,,,,,,,,,,,,,,,,,,,,,,,,,,,,,,,,,,,,,,,,,,,
10,2022-09-27 12:29:22,6,en,37717934,Yes,Yes,apple,Yes,Easy,Yes,,A little,No,,,,,No,,,,,pear,Yes,Somewhat difficult,Yes,,A little,No,,,,,No,,,,,Yes,No,Similar to what I am used to,Neither different nor similar,Non-intuitive,Non-intuitive,Neither easy nor difficult,Very difficult,You can work faster because it's keyboard driven.,You have to manually plug the usb in and out. You have to reflash after adding a breakpoint. The debugger has a steep learning curve.,The debugger is more user friendly. Connects with the vscode editor nicely. ,Where to reflash memory wasn't clear at the start. Has a slightly less steep learning curve but still not easy at first glance (if you don't know about vs code debugging).,26,Male,Python,,Yes,No,No experience,No,No,N/A,N/A,N/A,N/A,,No,No,Somewhat difficult,,,,,,,,,,,,,,,,,,,,,,,,,,,,,,,,,,,,,,,,,,,,,,,,,,,,,,,
11,2022-09-28 16:29:56,6,en,150048548,Yes,Yes,apple,Yes,Easy,Yes,,Yes,Yes,Neither easy nor difficult,Yes,,A lot,Yes,Neither easy nor difficult,Yes,,A lot,pear,No,,,,,No,,,,,No,,,,,Yes,No,Very similar to what I am used to,Very different from what I am used to,Intuitive,Absolutely non-intuitive,Easy,Very difficult,"I was unable to get the system to work properly, therefore I cannot assess any positive aspects related to it.","Incredibly unintuitive, for one needs to read a lot of documentation in order to start using the system.
The procedure with plugging the USB in, flashing, then unplugging is cumbersome, error-prone and unintuitive.
I could not get the memory address of any variable since the command msp430-elf-nm was not found in the system, and could therefore not read out the values of the variables using the debug prompt.
The need to put breakpoint commands inside the code, recompile, and then run it again, takes up too much time and is also error-prone.
It took me a while to realize that I need to stop the power to the device, then set it to constant voltage in order for the controller to reach the breakpoint. ","Very close to debugging a software system. The implemented watches, breakpoints in the source code, available variable names (and also the fact that pointers were dereferenced in the Variables interface) made it easy to observe the changes in values.","I personally did not like the fact that I had to open a separate monitor console for the serial output manually, even though that was easily done via the menu in VS Code.
",20,Male,Python,,Yes,Yes,Little experience,No,No,N/A,N/A,N/A,N/A,,No,No,Somewhat difficult,,,,,,,,,,,,,,,,,,,,,,,,,,,,,,,,,,,,,,,,,,,,,,,,,,,,,,,
12,2022-09-28 18:40:14,6,en,268779030,Yes,Yes,apple,Yes,Easy,Yes,,Yes,No,,,,,No,,,,,pear,No,,,,,No,,,,,No,,,,,Yes,No,Similar to what I am used to,Very different from what I am used to,Absolutely intuitive,Non-intuitive,Easy,Very difficult,Easy to find low level details of the program like the memory address of variables.,No GUI which makes using this debugger less intuitive. Not being able to visualize where the program is currently breaking also sucks. No easy way to see the human readable values of variables (maybe there is but I didn't really find one).,"The GUI makes debugging a lot more intuitive and easy to get started, also being able to hover over variables to see their value is very useful. Clicking buttons to step over, continue or step in is also very user-friendly.",Initially it was not clear to me that the monitor was running in a different terminal.,25,Male,C#,,Yes,Yes,Some experience,No,Yes,Yes,No,Yes,No,,No,No,Similiar to battery-powered embedded systems,,,,,,,,,,,,,,,,,,,,,,,,,,,,,,,,,,,,,,,,,,,,,,,,,,,,,,,
13,2022-09-29 10:35:33,6,en,1763509125,Yes,Yes,apple,Yes,Somewhat difficult,Other,"analyse the code, what it is ment to do",A little,No,,,,,No,,,,,pear,No,,,,,No,,,,,No,,,,,Yes,No,Very similar to what I am used to,Very different from what I am used to,Intuitive,Absolutely non-intuitive,Easy,Very difficult,non,many steps to start debuging. Very limited information on de bug/error the program run into ,no need to change code. Time saving. more user friendly interface ,"although better informed on the code and process, still limited information on the bug/error the program run into",36,Male,Python,,Yes,Yes,No experience,No,Yes,Yes,Yes,Yes,No,,No,No,Somewhat difficult,,,,,,,,,,,,,,,,,,,,,,,,,,,,,,,,,,,,,,,,,,,,,,,,,,,,,,,
14,2022-09-30 16:28:56,6,en,1046023620,Yes,Yes,apple,Yes,Easy,Yes,,Yes,No,,,,,No,,,,,pear,Yes,Somewhat difficult,Other,Noticed the mistake,No,No,,,,,No,,,,,Yes,No,Different from what I am used to,Very similar to what I am used to,Intuitive,Absolutely non-intuitive,Easy,Very difficult,It's  IDE independent ,"The 'wait' and 'int' was very unintuitive for me, also having to attach the device every time can be really tedious","The UI, not needing to flash every time, breakpoints separated from the source code",Not IDE independent,21,Male,Java,,Yes,Yes,Little experience,No,No,N/A,N/A,N/A,N/A,,Yes,No,Somewhat difficult,,,,,,,,,,,,,,,,,,,,,,,,,,,,,,,,,,,,,,,,,,,,,,,,,,,,,,,
15,2022-09-30 18:32:56,6,en,2065406343,Yes,Yes,apple,Yes,Easy,Yes,,Yes,No,,,,,No,,,,,pear,No,,,,,No,,,,,No,,,,,Yes,No,Similar to what I am used to,Very different from what I am used to,Intuitive,Absolutely non-intuitive,Easy,Very difficult,None?,"Only with commands, hard to remember the commands, hard to know the current state, not flexible, not intuitive","Use a graphic interface, easy to know where we are in the code, see the variables values, intuitive",I had sometimes an error saying that I had too many breakpoints?,27,Female,C#,,Yes,Yes,Little experience,No,Yes,Yes,Yes,Yes,No,,No,No,Somewhat difficult,,,,,,,,,,,,,,,,,,,,,,,,,,,,,,,,,,,,,,,,,,,,,,,,,,,,,,,
16,2022-10-04 12:11:46,6,en,1692036006,Yes,Yes,apple,No,,,,,No,,,,,No,,,,,pear,Yes,Easy,Other,Looking at .h files,No,No,,,,,Yes,Easy,Other,Reading the code,No,No,No,Very different from what I am used to,Different from what I am used to,Non-intuitive,Absolutely non-intuitive,Somewhat difficult,Very difficult,"It doesn't depend on VScode specific plugins.
So I could edit my source in Vim, for example, and still use this debugger.","The flash.sh script doesn't seem to actually upload to the device, I think.
It would be a lot nicer for me if this was just a makefile, which I am familiar with.
It would be nice if debug.sh allowed for command line options like setting baud rate, /dev/ port, etc.
That way I wouldn't need to run 'attach' every time.
More advanced line editing (vim keybinds :)?) would also be nice.
I never got breakpoints to work, so I can't comment on it other than I couldn't get them to work even after 30 minutes.","It's integrated with VScode, so I can see where my breakpoint is, set new ones, pause etc.","I have never used VScode before, so I had no idea where to look for debugging functions or even how to open code in multiple tabs!
If someone is used to Vim or CLion, they will not like system A.",23,Female,C/C++,,No,No,Some experience,Yes,Yes,Yes,No,Yes,Yes,,No,No,Similiar to battery-powered embedded systems,,,,,,,,,,,,,,,,,,,,,,,,,,,,,,,,,,,,,,,,,,,,,,,,,,,,,,,
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

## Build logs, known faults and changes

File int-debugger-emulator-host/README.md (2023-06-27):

# Intermittently-powered Systems Debugger: Emulator (host)

### Libraries
- [HighFive (c++ hdf5 library)](https://github.com/BlueBrain/HighFive)
- [Int Debugger Interface](https://github.com/TUDSSL/int-debugger-interface)

### Required:
- protobuf
- libhdf5-dev

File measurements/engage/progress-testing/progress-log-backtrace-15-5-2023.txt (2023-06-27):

(gdb) backtrace full
backtrace full
#0  memcpy (dst0=0x10009c00 <z80_memory+15360>, src0=<optimized out>, len0=<optimized out>) at ../../../../../../newlib-4.3.0.20230120/newlib/libc/machine/arm/../../string/memcpy.c:59
        dst = <optimized out>
        src = 0x51016ede <error: Cannot access memory at address 0x51016ede>
        save = 0x10009c00 <z80_memory+15360>
#1  0x0001bfba in mpatch_write (high=268475903, low=268475392, mp_apply=0x51016e0c) at /home/jasper/Music/latest-testing/ENGAGE/software/libs/mpatch/mpatch/mpatch.c:473
        size = 512
        dst = 0x10009c00 <z80_memory+15360> ""
        offset = <optimized out>
#2  mpatch_apply (mp_apply=0x51016e0c, low=268475392, high=268475903, applied=0x100188dc, write=false) at /home/jasper/Music/latest-testing/ENGAGE/software/libs/mpatch/mpatch/mpatch.c:489
        p_overlap = <optimized out>
Backtrace stopped: previous frame identical to this frame (corrupt stack?)
(gdb)

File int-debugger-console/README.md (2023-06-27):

## Installation
Install all python requirements

``` $ pip3 install -r requirements.txt ```

## Usage 
Before starting the program, the file 'dips_testing.json' needs to be configured. 
There are two important options that need to be configured. 
The checkpointing-related functions `checkpoint_function` and `restore_function` needs to be configured to your own functions. 
By default it assumes that the functions are `checkpoint` and `restore`. 
The last important option is that `chip` needs to be configured to the right chip. 

The main entry point is `main.py`. You can enter the PUT as argument:

``` $ python main.py ../example-program/put.bin```

The next step is to connect to DIPS. This step also connects and halts the DUT. This can be done by running:

``` $ connect```

## Check for memory faults
Inside the file `dips_testing.json`, the `memcheck` fields need to be configured to your own project. The regions are the regions that are checked for memory differences. It is important to generate the folder `dumps` in order to store the memory dumps. 

To start the memory compare, run `dips_mem_check`

The check will automatically stop if a memory inconsistency is detected

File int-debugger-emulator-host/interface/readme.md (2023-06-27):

nanopb.proto v0.4.5 required since the submodule uses it as include extensively.
https://github.com/nanopb/nanopb

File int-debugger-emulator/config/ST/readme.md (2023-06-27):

files are here just not to break the ST project structure. Do not modify if possible.

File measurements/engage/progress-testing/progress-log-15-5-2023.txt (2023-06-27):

Square wave:
voltage 4100mV
Duty cycle 20%, period 3S
Takeover 3000mV, Debug takeover enabled

settings .json:
  "memcheck": {
     "regions": {
    },
    "checkpoint_function": "checkpoint.c:33",
    "restore_function": "restore_emulator",
    "timeout": 300,
    "only_checkpointing": true
  },
  
python main.py emulator.elf 
(gdb) connect
found port: ttyACM1
tar ext /dev/ttyACM1
Remote debugging using /dev/ttyACM1
mon auto_scan
Target voltage: 3.0V
Available Targets:
No. Att Driver
 1      Ambiq Apollo 3 M4
attach 1
Attaching to program: /home/jasper/git/Intermittent_software/int-debugger-console/emulator.elf, Remote target
memcpy (dst0=0x10007400 <z80_memory+5120>, src0=<optimized out>, len0=<optimized out>) at ../../../../../../newlib-4.3.0.20230120/newlib/libc/machine/arm/../../string/memcpy.c:59
59	../../../../../../newlib-4.3.0.20230120/newlib/libc/machine/arm/../../string/memcpy.c: No such file or directory.
^connected
(gdb) dips_mem_check
Starting memory automated testing procedure....

Using checkpoint and restore functions from default configuration

Add checkpoint and restore as arguments to change this

set pagination off
set print pretty
mon interrupt_on_power_failure enable
b checkpoint.c:33
Breakpoint 1 at 0x1bd84: file /home/jasper/Music/latest-testing/ENGAGE/software/libs/mpatch/checkpoint/checkpoint.c, line 33.
Note: automatically using hardware breakpoints for read-only addresses.
[['&"b checkpoint.c:33\\n"', '~"Breakpoint 1 at 0x1bd84: file /home/jasper/Music/latest-testing/ENGAGE/software/libs/mpatch/checkpoint/checkpoint.c, line 33.\\n"', '=breakpoint-created,bkpt={number="1",type="breakpoint",disp="keep",enabled="y",addr="0x0001bd84",func="checkpoint_commit",file="/home/jasper/Music/latest-testing/ENGAGE/software/libs/mpatch/checkpoint/checkpoint.c",fullname="/home/jasper/Music/latest-testing/ENGAGE/software/libs/mpatch/checkpoint/checkpoint.c",line="33",thread-groups=["i1"],times="0",original-location="checkpoint.c:33"}', '~"Note: automatically using hardware breakpoints for read-only addresses.\\n"', '^done', '(gdb) '], [{'type': 'log', 'message': None, 'payload': 'b checkpoint.c:33\n', 'stream': 'stdout'}, {'type': 'console', 'message': None, 'payload': 'Breakpoint 1 at 0x1bd84: file /home/jasper/Music/latest-testing/ENGAGE/software/libs/mpatch/checkpoint/checkpoint.c, line 33.\n', 'stream': 'stdout'}, {'type': 'notify', 'message': 'breakpoint-created', 'payload': {'bkpt': {'number': '1', 'type': 'breakpoint', 'disp': 'keep', 'enabled': 'y', 'addr': '0x0001bd84', 'func': 'checkpoint_commit', 'file': '/home/jasper/Music/latest-testing/ENGAGE/software/libs/mpatch/checkpoint/checkpoint.c', 'fullname': '/home/jasper/Music/latest-testing/ENGAGE/software/libs/mpatch/checkpoint/checkpoint.c', 'line': '33', 'thread-groups': ['i1'], 'times': '0', 'original-location': 'checkpoint.c:33'}}, 'token': None, 'stream': 'stdout'}, {'type': 'console', 'message': None, 'payload': 'Note: automatically using hardware breakpoints for read-only addresses.\n', 'stream': 'stdout'}, {'type': 'result', 'message': 'done', 'payload': None, 'token': None, 'stream': 'stdout'}]]
b restore_emulator
Breakpoint 2 at 0x1bd0a: file /home/jasper/Music/latest-testing/ENGAGE/software/libs/emulator/checkpoint_emulator.h, line 7.
[['&"b restore_emulator\\n"', '~"Breakpoint 2 at 0x1bd0a: file /home/jasper/Music/latest-testing/ENGAGE/software/libs/emulator/checkpoint_emulator.h, line 7.\\n"', '=breakpoint-created,bkpt={number="2",type="breakpoint",disp="keep",enabled="y",addr="0x0001bd0a",func="restore_emulator",file="/home/jasper/Music/latest-testing/ENGAGE/software/libs/emulator/checkpoint_emulator.h",fullname="/home/jasper/Music/latest-testing/ENGAGE/software/libs/emulator/checkpoint_emulator.h",line="7",thread-groups=["i1"],times="0",original-location="restore_emulator"}', '^done', '(gdb) '], [{'type': 'log', 'message': None, 'payload': 'b restore_emulator\n', 'stream': 'stdout'}, {'type': 'console', 'message': None, 'payload': 'Breakpoint 2 at 0x1bd0a: file /home/jasper/Music/latest-testing/ENGAGE/software/libs/emulator/checkpoint_emulator.h, line 7.\n', 'stream': 'stdout'}, {'type': 'notify', 'message': 'breakpoint-created', 'payload': {'bkpt': {'number': '2', 'type': 'breakpoint', 'disp': 'keep', 'enabled': 'y', 'addr': '0x0001bd0a', 'func': 'restore_emulator', 'file': '/home/jasper/Music/latest-testing/ENGAGE/software/libs/emulator/checkpoint_emulator.h', 'fullname': '/home/jasper/Music/latest-testing/ENGAGE/software/libs/emulator/checkpoint_emulator.h', 'line': '7', 'thread-groups': ['i1'], 'times': '0', 'original-location': 'restore_emulator'}}, 'token': None, 'stream': 'stdout'}, {'type': 'result', 'message': 'done', 'payload': None, 'token': None, 'stream': 'stdout'}]]
~"Test memory check initialized"
~"starting script now"
2023-05-15 18:04:57.198328 restore triggered 1

2023-05-15 18:05:01.118428 checkpoint triggered 1

2023-05-15 18:05:03.167483 restarted

2023-05-15 18:05:03.747958 restore triggered 2

2023-05-15 18:05:05.208473 checkpoint triggered 2

2023-05-15 18:05:07.297541 restarted

2023-05-15 18:05:07.878173 restore triggered 3

2023-05-15 18:05:09.338396 checkpoint triggered 3

2023-05-15 18:05:11.427382 restarted

2023-05-15 18:05:12.016985 restore triggered 4

2023-05-15 18:05:13.468100 checkpoint triggered 4

2023-05-15 18:05:15.557330 restarted

2023-05-15 18:05:16.137524 restore triggered 5

2023-05-15 18:05:17.606910 checkpoint triggered 5

2023-05-15 18:05:19.657243 restarted

2023-05-15 18:05:20.237297 restore triggered 6

2023-05-15 18:05:23.317273 restarted

2023-05-15 18:05:23.899061 restore triggered 7

2023-05-15 18:05:25.408718 checkpoint triggered 6

2023-05-15 18:05:27.497216 restarted

2023-05-15 18:05:28.077404 restore triggered 8

2023-05-15 18:05:29.538404 checkpoint triggered 7

2023-05-15 18:05:31.627045 restarted

2023-05-15 18:05:32.208156 restore triggered 9

2023-05-15 18:05:33.668063 checkpoint triggered 8

2023-05-15 18:05:35.757093 restarted

2023-05-15 18:05:36.337426 restore triggered 10

2023-05-15 18:05:37.797790 checkpoint triggered 9

2023-05-15 18:05:39.886853 restarted

2023-05-15 18:05:40.468397 restore triggered 11

2023-05-15 18:05:41.928348 checkpoint triggered 10

2023-05-15 18:05:44.016817 restarted

2023-05-15 18:05:44.597487 restore triggered 12

2023-05-15 18:05:46.058153 checkpoint triggered 11

2023-05-15 18:05:48.107212 restarted

2023-05-15 18:05:48.687545 restore triggered 13

2023-05-15 18:05:50.148464 checkpoint triggered 12

2023-05-15 18:05:52.227097 restarted

2023-05-15 18:05:52.808526 restore triggered 14

2023-05-15 18:05:54.268208 checkpoint triggered 13

2023-05-15 18:05:56.346965 restarted

2023-05-15 18:05:56.927347 restore triggered 15

2023-05-15 18:06:00.016616 restarted

2023-05-15 18:06:00.598963 restore triggered 16

2023-05-15 18:06:03.767064 restarted

2023-05-15 18:06:04.348374 restore triggered 17

2023-05-15 18:06:05.757746 checkpoint triggered 14

2023-05-15 18:06:07.867178 restarted

2023-05-15 18:06:08.447539 restore triggered 18

2023-05-15 18:06:09.907548 checkpoint triggered 15

2023-05-15 18:06:11.996688 restarted

2023-05-15 18:06:12.577689 restore triggered 19

2023-05-15 18:06:14.038288 checkpoint triggered 16

2023-05-15 18:06:16.126465 restarted

2023-05-15 18:06:16.707903 restore triggered 20

2023-05-15 18:06:18.176111 checkpoint triggered 17

2023-05-15 18:06:20.226425 restarted

2023-05-15 18:06:20.806444 restore triggered 21

2023-05-15 18:06:23.896886 restarted

2023-05-15 18:06:24.477279 restore triggered 22

2023-05-15 18:06:27.566408 restarted

2023-05-15 18:06:28.147438 restore triggered 23

2023-05-15 18:06:31.316242 restarted

2023-05-15 18:06:31.897154 restore triggered 24

2023-05-15 18:06:33.298652 checkpoint triggered 18

2023-05-15 18:06:35.416169 restarted

2023-05-15 18:06:35.996985 restore triggered 25

2023-05-15 18:06:39.106479 restarted

2023-05-15 18:06:39.686688 restore triggered 26

2023-05-15 18:06:41.137158 checkpoint triggered 19

2023-05-15 18:06:43.226137 restarted

2023-05-15 18:06:43.806673 restore triggered 27

2023-05-15 18:06:45.209574 checkpoint triggered 20

2023-05-15 18:06:47.326114 restarted

2023-05-15 18:06:47.906541 restore triggered 28

2023-05-15 18:06:51.026082 restarted

2023-05-15 18:06:51.606589 restore triggered 29

2023-05-15 18:06:53.016273 checkpoint triggered 21

2023-05-15 18:06:55.116130 restarted

2023-05-15 18:06:55.696552 restore triggered 30

2023-05-15 18:06:57.156663 checkpoint triggered 22

2023-05-15 18:06:59.246561 restarted

2023-05-15 18:06:59.826726 restore triggered 31

2023-05-15 18:07:01.315718 checkpoint triggered 23

2023-05-15 18:07:03.375964 restarted

2023-05-15 18:07:03.957041 restore triggered 32

2023-05-15 18:07:05.416400 checkpoint triggered 24

2023-05-15 18:07:07.506356 restarted

2023-05-15 18:07:08.086369 restore triggered 33

2023-05-15 18:07:09.547494 checkpoint triggered 25

2023-05-15 18:07:11.635699 restarted

2023-05-15 18:07:12.215921 restore triggered 34

2023-05-15 18:07:13.676779 checkpoint triggered 26

2023-05-15 18:07:15.735837 restarted

2023-05-15 18:07:16.317155 restore triggered 35

2023-05-15 18:07:19.475722 restarted

2023-05-15 18:07:20.056639 restore triggered 36

2023-05-15 18:07:21.466400 checkpoint triggered 27

2023-05-15 18:07:23.576031 restarted

2023-05-15 18:07:24.156039 restore triggered 37

2023-05-15 18:07:27.275634 restarted

2023-05-15 18:07:27.856483 restore triggered 38

2023-05-15 18:07:29.266419 checkpoint triggered 28

2023-05-15 18:07:31.365595 restarted

2023-05-15 18:07:31.946928 restore triggered 39

2023-05-15 18:07:33.406506 checkpoint triggered 29

2023-05-15 18:07:35.495605 restarted

2023-05-15 18:07:36.076967 restore triggered 40

2023-05-15 18:07:37.535739 checkpoint triggered 30

2023-05-15 18:07:39.625609 restarted

2023-05-15 18:07:40.205998 restore triggered 41

2023-05-15 18:07:41.665999 checkpoint triggered 31

2023-05-15 18:07:43.765303 restarted

2023-05-15 18:07:44.346718 restore triggered 42

2023-05-15 18:07:45.755649 checkpoint triggered 32

2023-05-15 18:07:47.855251 restarted

2023-05-15 18:07:48.445582 restore triggered 43

2023-05-15 18:07:49.906503 checkpoint triggered 33

2023-05-15 18:07:51.995528 restarted

2023-05-15 18:07:52.586705 restore triggered 44

2023-05-15 18:07:54.006151 checkpoint triggered 34

2023-05-15 18:07:56.095046 restarted

2023-05-15 18:07:56.686963 restore triggered 45

2023-05-15 18:07:58.145680 checkpoint triggered 35

2023-05-15 18:08:00.235126 restarted

2023-05-15 18:08:00.825764 restore triggered 46

2023-05-15 18:08:02.286496 checkpoint triggered 36

2023-05-15 18:08:04.375476 restarted

2023-05-15 18:08:04.965441 restore triggered 47

2023-05-15 18:08:06.376851 checkpoint triggered 37

2023-05-15 18:08:08.465267 restarted

2023-05-15 18:08:09.055961 restore triggered 48

2023-05-15 18:08:10.515615 checkpoint triggered 38

2023-05-15 18:08:12.604854 restarted

2023-05-15 18:08:13.185490 restore triggered 49

2023-05-15 18:08:14.646144 checkpoint triggered 39

2023-05-15 18:08:16.735019 restarted

2023-05-15 18:08:17.315935 restore triggered 50

2023-05-15 18:08:20.375078 restarted

2023-05-15 18:08:20.955360 restore triggered 51

2023-05-15 18:08:22.415196 checkpoint triggered 40

2023-05-15 18:08:24.504878 restarted

2023-05-15 18:08:25.096134 restore triggered 52

2023-05-15 18:08:26.555107 checkpoint triggered 41

2023-05-15 18:08:28.644787 restarted

2023-05-15 18:08:29.244891 restore triggered 53

2023-05-15 18:08:32.284680 restarted

2023-05-15 18:08:32.876043 restore triggered 54

2023-05-15 18:08:36.035045 restarted

2023-05-15 18:08:36.625629 restore triggered 55

2023-05-15 18:08:38.085947 checkpoint triggered 42

2023-05-15 18:08:40.134631 restarted

2023-05-15 18:08:40.715859 restore triggered 56

2023-05-15 18:08:42.175822 checkpoint triggered 43

2023-05-15 18:08:44.264481 restarted

2023-05-15 18:08:44.845832 restore triggered 57

2023-05-15 18:08:47.954592 restarted

2023-05-15 18:08:48.546278 restore triggered 58

2023-05-15 18:08:49.956159 checkpoint triggered 44

2023-05-15 18:08:52.054434 restarted

2023-05-15 18:08:52.635630 restore triggered 59

2023-05-15 18:08:54.095366 checkpoint triggered 45

2023-05-15 18:08:56.184683 restarted

2023-05-15 18:08:56.775295 restore triggered 60

2023-05-15 18:08:58.235226 checkpoint triggered 46

2023-05-15 18:09:00.325009 restarted

2023-05-15 18:09:00.915212 restore triggered 61

2023-05-15 18:09:03.994282 restarted

2023-05-15 18:09:04.594144 restore triggered 62

2023-05-15 18:09:06.006043 checkpoint triggered 47

2023-05-15 18:09:08.094561 restarted

2023-05-15 18:09:08.686142 restore triggered 63

2023-05-15 18:09:10.145523 checkpoint triggered 48

2023-05-15 18:09:12.234404 restarted

2023-05-15 18:09:12.826108 restore triggered 64

2023-05-15 18:09:14.235448 checkpoint triggered 49

2023-05-15 18:09:16.364100 restarted

2023-05-15 18:09:16.955240 restore triggered 65

2023-05-15 18:09:20.024492 restarted

2023-05-15 18:09:20.615371 restore triggered 66

2023-05-15 18:09:22.026089 checkpoint triggered 50

2023-05-15 18:09:24.124363 restarted

2023-05-15 18:09:24.715355 restore triggered 67

2023-05-15 18:09:26.174086 checkpoint triggered 51

2023-05-15 18:09:28.224181 restarted

2023-05-15 18:09:28.815367 restore triggered 68

2023-05-15 18:09:31.944377 restarted

2023-05-15 18:09:32.534415 restore triggered 69

2023-05-15 18:09:33.945242 checkpoint triggered 52

2023-05-15 18:09:36.074539 restarted

2023-05-15 18:09:36.664681 restore triggered 70

2023-05-15 18:09:39.734010 restarted

2023-05-15 18:09:40.325283 restore triggered 71

2023-05-15 18:09:41.734321 checkpoint triggered 53

2023-05-15 18:09:43.833866 restarted

2023-05-15 18:09:44.433866 restore triggered 72

2023-05-15 18:09:45.894838 checkpoint triggered 54

2023-05-15 18:09:47.983787 restarted

2023-05-15 18:09:48.575289 restore triggered 73

2023-05-15 18:09:49.985880 checkpoint triggered 55

2023-05-15 18:09:52.123679 restarted

2023-05-15 18:09:52.714739 restore triggered 74

2023-05-15 18:09:54.125036 checkpoint triggered 56

2023-05-15 18:09:56.223978 restarted

2023-05-15 18:09:56.824140 restore triggered 75

2023-05-15 18:09:58.234091 checkpoint triggered 57

2023-05-15 18:10:00.324160 restarted

2023-05-15 18:10:00.924911 restore triggered 76

2023-05-15 18:10:02.385800 checkpoint triggered 58

2023-05-15 18:10:04.473555 restarted

2023-05-15 18:10:05.083820 restore triggered 77

2023-05-15 18:10:06.504500 checkpoint triggered 59

2023-05-15 18:10:08.573934 restarted

2023-05-15 18:10:09.174028 restore triggered 78

2023-05-15 18:10:10.634339 checkpoint triggered 60

2023-05-15 18:10:12.693689 restarted

2023-05-15 18:10:13.294586 restore triggered 79

2023-05-15 18:10:14.773338 checkpoint triggered 61

2023-05-15 18:10:16.873714 restarted

2023-05-15 18:10:17.464143 restore triggered 80

2023-05-15 18:10:18.925233 checkpoint triggered 62

2023-05-15 18:10:21.023615 restarted

2023-05-15 18:10:21.624158 restore triggered 81

2023-05-15 18:10:23.034699 checkpoint triggered 63

2023-05-15 18:10:25.123450 restarted

2023-05-15 18:10:25.724336 restore triggered 82

2023-05-15 18:10:27.184952 checkpoint triggered 64

2023-05-15 18:10:29.273401 restarted

2023-05-15 18:10:29.874153 restore triggered 83

2023-05-15 18:10:31.284757 checkpoint triggered 65

2023-05-15 18:10:33.373729 restarted

2023-05-15 18:10:33.974566 restore triggered 84

2023-05-15 18:10:35.384831 checkpoint triggered 66

2023-05-15 18:10:37.523243 restarted

2023-05-15 18:10:38.123509 restore triggered 85

2023-05-15 18:10:41.183457 restarted

2023-05-15 18:10:41.784657 restore triggered 86

2023-05-15 18:10:43.194637 checkpoint triggered 67

2023-05-15 18:10:45.243502 restarted

2023-05-15 18:10:45.843220 restore triggered 87

2023-05-15 18:10:48.983126 restarted

2023-05-15 18:10:49.583594 restore triggered 88

2023-05-15 18:10:52.653082 restarted

2023-05-15 18:10:53.254444 restore triggered 89

2023-05-15 18:10:56.322940 restarted

2023-05-15 18:10:56.923644 restore triggered 90

2023-05-15 18:10:59.993111 restarted

2023-05-15 18:11:00.594940 restore triggered 91

2023-05-15 18:11:03.673033 restarted

2023-05-15 18:11:04.273877 restore triggered 92

2023-05-15 18:11:05.684531 checkpoint triggered 68

2023-05-15 18:11:07.772816 restarted

2023-05-15 18:11:08.373873 restore triggered 93

2023-05-15 18:11:09.783454 checkpoint triggered 69

2023-05-15 18:11:11.892781 restarted

2023-05-15 18:11:12.493555 restore triggered 94

2023-05-15 18:11:13.904079 checkpoint triggered 70

2023-05-15 18:11:16.012711 restarted

2023-05-15 18:11:16.623439 restore triggered 95

2023-05-15 18:11:18.042546 checkpoint triggered 71

2023-05-15 18:11:20.172836 restarted

2023-05-15 18:11:20.783360 restore triggered 96

2023-05-15 18:11:22.193859 checkpoint triggered 72

2023-05-15 18:11:24.282714 restarted

2023-05-15 18:11:24.884148 restore triggered 97

2023-05-15 18:11:26.293308 checkpoint triggered 73

2023-05-15 18:11:28.422654 restarted

2023-05-15 18:11:29.032502 restore triggered 98

2023-05-15 18:11:30.443189 checkpoint triggered 74

2023-05-15 18:11:32.532680 restarted

2023-05-15 18:11:33.133867 restore triggered 99

2023-05-15 18:11:34.543535 checkpoint triggered 75

2023-05-15 18:11:36.633046 restarted

2023-05-15 18:11:37.233932 restore triggered 100

2023-05-15 18:11:38.693425 checkpoint triggered 76

2023-05-15 18:11:40.782530 restarted

2023-05-15 18:11:41.384390 restore triggered 101

2023-05-15 18:11:42.792962 checkpoint triggered 77

2023-05-15 18:11:44.882616 restarted

2023-05-15 18:11:45.492536 restore triggered 102

2023-05-15 18:11:46.953027 checkpoint triggered 78

2023-05-15 18:11:49.002693 restarted

2023-05-15 18:11:49.613488 restore triggered 103

2023-05-15 18:11:51.023557 checkpoint triggered 79

2023-05-15 18:11:53.162271 restarted

2023-05-15 18:11:53.772894 restore triggered 104

2023-05-15 18:11:56.832290 restarted

2023-05-15 18:11:57.443569 restore triggered 105

2023-05-15 18:11:58.852767 checkpoint triggered 80

2023-05-15 18:12:00.942322 restarted

2023-05-15 18:12:01.543545 restore triggered 106

2023-05-15 18:12:02.953338 checkpoint triggered 81

2023-05-15 18:12:05.082328 restarted

2023-05-15 18:12:05.682807 restore triggered 107

2023-05-15 18:12:07.093531 checkpoint triggered 82

2023-05-15 18:12:09.182300 restarted

2023-05-15 18:12:09.783448 restore triggered 108

2023-05-15 18:12:11.192574 checkpoint triggered 83

2023-05-15 18:12:13.302491 restarted

2023-05-15 18:12:13.912862 restore triggered 109

2023-05-15 18:12:17.002028 restarted

2023-05-15 18:12:17.613128 restore triggered 110

2023-05-15 18:12:19.023283 checkpoint triggered 84

2023-05-15 18:12:21.112132 restarted

2023-05-15 18:12:21.722967 restore triggered 111

2023-05-15 18:12:24.761819 restarted

2023-05-15 18:12:25.372989 restore triggered 112

2023-05-15 18:12:28.431932 restarted

2023-05-15 18:12:29.043183 restore triggered 113

2023-05-15 18:12:30.512448 checkpoint triggered 85

2023-05-15 18:12:32.561849 restarted

2023-05-15 18:12:33.172118 restore triggered 114

2023-05-15 18:12:34.622685 checkpoint triggered 86

2023-05-15 18:12:36.711793 restarted

2023-05-15 18:12:37.313199 restore triggered 115

2023-05-15 18:12:40.351920 restarted

2023-05-15 18:12:40.952827 restore triggered 116

2023-05-15 18:12:44.101658 restarted

2023-05-15 18:12:44.703125 restore triggered 117

2023-05-15 18:12:46.104579 checkpoint triggered 87

2023-05-15 18:12:48.201964 restarted

2023-05-15 18:12:48.803028 restore triggered 118

2023-05-15 18:12:50.262316 checkpoint triggered 88

2023-05-15 18:12:52.351718 restarted

2023-05-15 18:12:52.952123 restore triggered 119

2023-05-15 18:12:54.355382 checkpoint triggered 89

2023-05-15 18:12:56.451695 restarted

2023-05-15 18:12:57.053198 restore triggered 120

2023-05-15 18:12:58.512070 checkpoint triggered 90

2023-05-15 18:13:00.611679 restarted

2023-05-15 18:13:01.221224 restore triggered 121

2023-05-15 18:13:02.625317 checkpoint triggered 91

2023-05-15 18:13:04.701624 restarted

2023-05-15 18:13:05.302230 restore triggered 122

2023-05-15 18:13:06.762463 checkpoint triggered 92

2023-05-15 18:13:08.851964 restarted

2023-05-15 18:13:09.451752 restore triggered 123

2023-05-15 18:13:10.854048 checkpoint triggered 93

2023-05-15 18:13:12.951405 restarted

2023-05-15 18:13:13.552032 restore triggered 124

2023-05-15 18:13:15.012812 checkpoint triggered 94

2023-05-15 18:13:17.101460 restarted

2023-05-15 18:13:17.702269 restore triggered 125

2023-05-15 18:13:20.781639 restarted

2023-05-15 18:13:21.382694 restore triggered 126

2023-05-15 18:13:24.501337 restarted

2023-05-15 18:13:25.101851 restore triggered 127

2023-05-15 18:13:26.504967 checkpoint triggered 95

2023-05-15 18:13:28.631390 restarted

2023-05-15 18:13:29.231443 restore triggered 128

2023-05-15 18:13:30.641272 checkpoint triggered 96

2023-05-15 18:13:32.731390 restarted

2023-05-15 18:13:33.332657 restore triggered 129

2023-05-15 18:13:34.742494 checkpoint triggered 97

2023-05-15 18:13:36.881234 restarted

2023-05-15 18:13:37.481401 restore triggered 130

2023-05-15 18:13:38.884094 checkpoint triggered 98

2023-05-15 18:13:40.971193 restarted

2023-05-15 18:13:41.571616 restore triggered 131

2023-05-15 18:13:43.032185 checkpoint triggered 99

2023-05-15 18:13:45.121087 restarted

2023-05-15 18:13:45.722450 restore triggered 132

2023-05-15 18:13:46.923524 checkpoint triggered 100

2023-05-15 18:13:48.991107 restarted

2023-05-15 18:13:49.591393 restore triggered 133

2023-05-15 18:13:51.041761 checkpoint triggered 101

2023-05-15 18:13:53.130947 restarted

2023-05-15 18:13:53.732310 restore triggered 134

2023-05-15 18:13:55.191397 checkpoint triggered 102

2023-05-15 18:13:57.240999 restarted

2023-05-15 18:13:57.841766 restore triggered 135

2023-05-15 18:13:59.302351 checkpoint triggered 103

2023-05-15 18:14:01.380740 restarted

2023-05-15 18:14:01.981355 restore triggered 136

2023-05-15 18:14:05.130734 restarted

2023-05-15 18:14:05.721673 restore triggered 137

2023-05-15 18:14:07.124072 checkpoint triggered 104

2023-05-15 18:14:09.251337 restarted

2023-05-15 18:14:12.454347 restarted

2023-05-15 18:14:15.657046 restarted

2023-05-15 18:14:18.860124 restarted

2023-05-15 18:14:22.060569 restarted

2023-05-15 18:14:25.263399 restarted

2023-05-15 18:14:28.466421 restarted

2023-05-15 18:14:31.669661 restarted

2023-05-15 18:14:34.872124 restarted

2023-05-15 18:14:38.074398 restarted

2023-05-15 18:14:41.277422 restarted

2023-05-15 18:14:44.480411 restarted

2023-05-15 18:14:47.683767 restarted

2023-05-15 18:14:50.886686 restarted

2023-05-15 18:14:54.088823 restarted

2023-05-15 18:14:57.292076 restarted

2023-05-15 18:15:00.494294 restarted

2023-05-15 18:15:03.696834 restarted

2023-05-15 18:15:06.900133 restarted

2023-05-15 18:15:10.103145 restarted

2023-05-15 18:15:13.305323 restarted

2023-05-15 18:15:16.507392 restarted

2023-05-15 18:15:19.710464 restarted

2023-05-15 18:15:22.913393 restarted

2023-05-15 18:15:26.116278 restarted

2023-05-15 18:15:29.318968 restarted

2023-05-15 18:15:32.522026 restarted

2023-05-15 18:15:35.724328 restarted

2023-05-15 18:15:38.927026 restarted

2023-05-15 18:15:42.129864 restarted

2023-05-15 18:15:45.332126 restarted

2023-05-15 18:15:48.535479 restarted

2023-05-15 18:15:51.737638 restarted

2023-05-15 18:15:54.939910 restarted

2023-05-15 18:15:58.143259 restarted

2023-05-15 18:16:01.345523 restarted

2023-05-15 18:16:04.547690 restarted

2023-05-15 18:16:07.750977 restarted

2023-05-15 18:16:10.954056 restarted

2023-05-15 18:16:14.157646 restarted

2023-05-15 18:16:17.360207 restarted

2023-05-15 18:16:20.563542 restarted

2023-05-15 18:16:23.766887 restarted

2023-05-15 18:16:26.969413 restarted

2023-05-15 18:16:30.172270 restarted

2023-05-15 18:16:33.375354 restarted

2023-05-15 18:16:36.577713 restarted

2023-05-15 18:16:39.781071 restarted

2023-05-15 18:16:42.984301 restarted

2023-05-15 18:16:46.187012 restarted

2023-05-15 18:16:49.389971 restarted

2023-05-15 18:16:52.592423 restarted

2023-05-15 18:16:55.788793 restarted

2023-05-15 18:16:58.991158 restarted

2023-05-15 18:17:02.189082 restarted

2023-05-15 18:17:05.391935 restarted

2023-05-15 18:17:08.594029 restarted

2023-05-15 18:17:11.796905 restarted

2023-05-15 18:17:14.998564 restarted

2023-05-15 18:17:18.200957 restarted

2023-05-15 18:17:21.404273 restarted

2023-05-15 18:17:24.607192 restarted

2023-05-15 18:17:27.810355 restarted

2023-05-15 18:17:31.013498 restarted

2023-05-15 18:17:34.216485 restarted

2023-05-15 18:17:37.418340 restarted

2023-05-15 18:17:40.621031 restarted

2023-05-15 18:17:43.823209 restarted

2023-05-15 18:17:47.025435 restarted

2023-05-15 18:17:50.227635 restarted

2023-05-15 18:17:53.430573 restarted

2023-05-15 18:17:56.633766 restarted

2023-05-15 18:17:59.836382 restarted

2023-05-15 18:18:03.038335 restarted

2023-05-15 18:18:06.241328 restarted

2023-05-15 18:18:09.444285 restarted

2023-05-15 18:18:12.646395 restarted

2023-05-15 18:18:15.848692 restarted

2023-05-15 18:18:19.050960 restarted

2023-05-15 18:18:22.254024 restarted

2023-05-15 18:18:25.456750 restarted

2023-05-15 18:18:28.658756 restarted

2023-05-15 18:18:31.860995 restarted

2023-05-15 18:18:35.063234 restarted

2023-05-15 18:18:38.265403 restarted

2023-05-15 18:18:41.467682 restarted

2023-05-15 18:18:44.670862 restarted

2023-05-15 18:18:47.872975 restarted

2023-05-15 18:18:51.075242 restarted

2023-05-15 18:18:54.277609 restarted

2023-05-15 18:18:57.480690 restarted

2023-05-15 18:19:00.682942 restarted

2023-05-15 18:19:03.885438 restarted

2023-05-15 18:19:07.086843 restarted

[['^done', '(gdb) '], [{'type': 'result', 'message': 'done', 'payload': None, 'token': None, 'stream': 'stdout'}]]
2023-05-15 18:19:07.287379 Errors found in application, no checkpoint detected in the last 300 seconds.

d 1
Cannot execute this command while the target is running.
Use the "interrupt" command to stop the target
and then try again.
d 2
Cannot execute this command while the target is running.
Use the "interrupt" command to stop the target
and then try again.
mon interrupt_on_power_failure disable
Cannot execute this command while the target is running.
Use the "interrupt" command to stop the target
and then try again.

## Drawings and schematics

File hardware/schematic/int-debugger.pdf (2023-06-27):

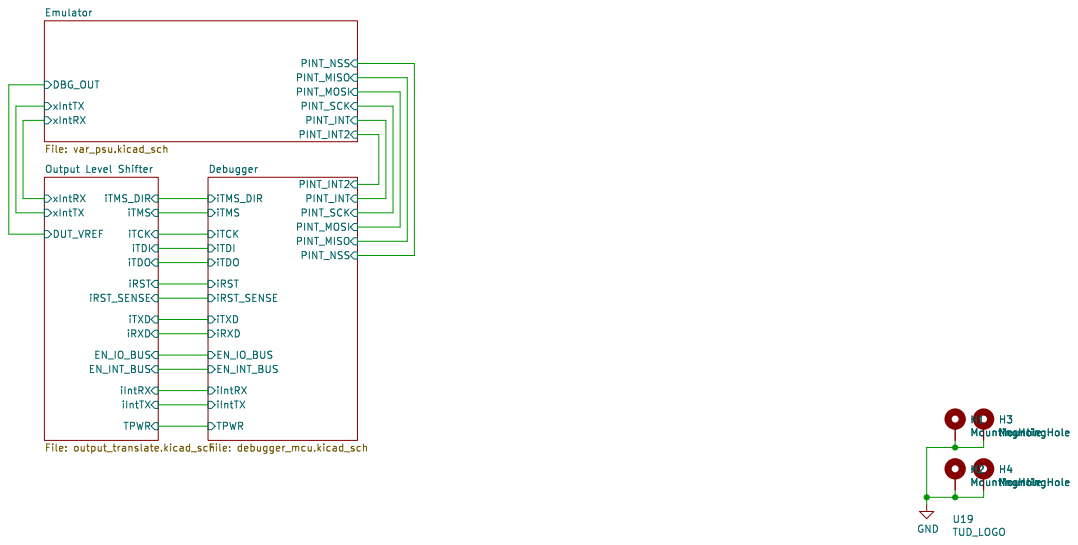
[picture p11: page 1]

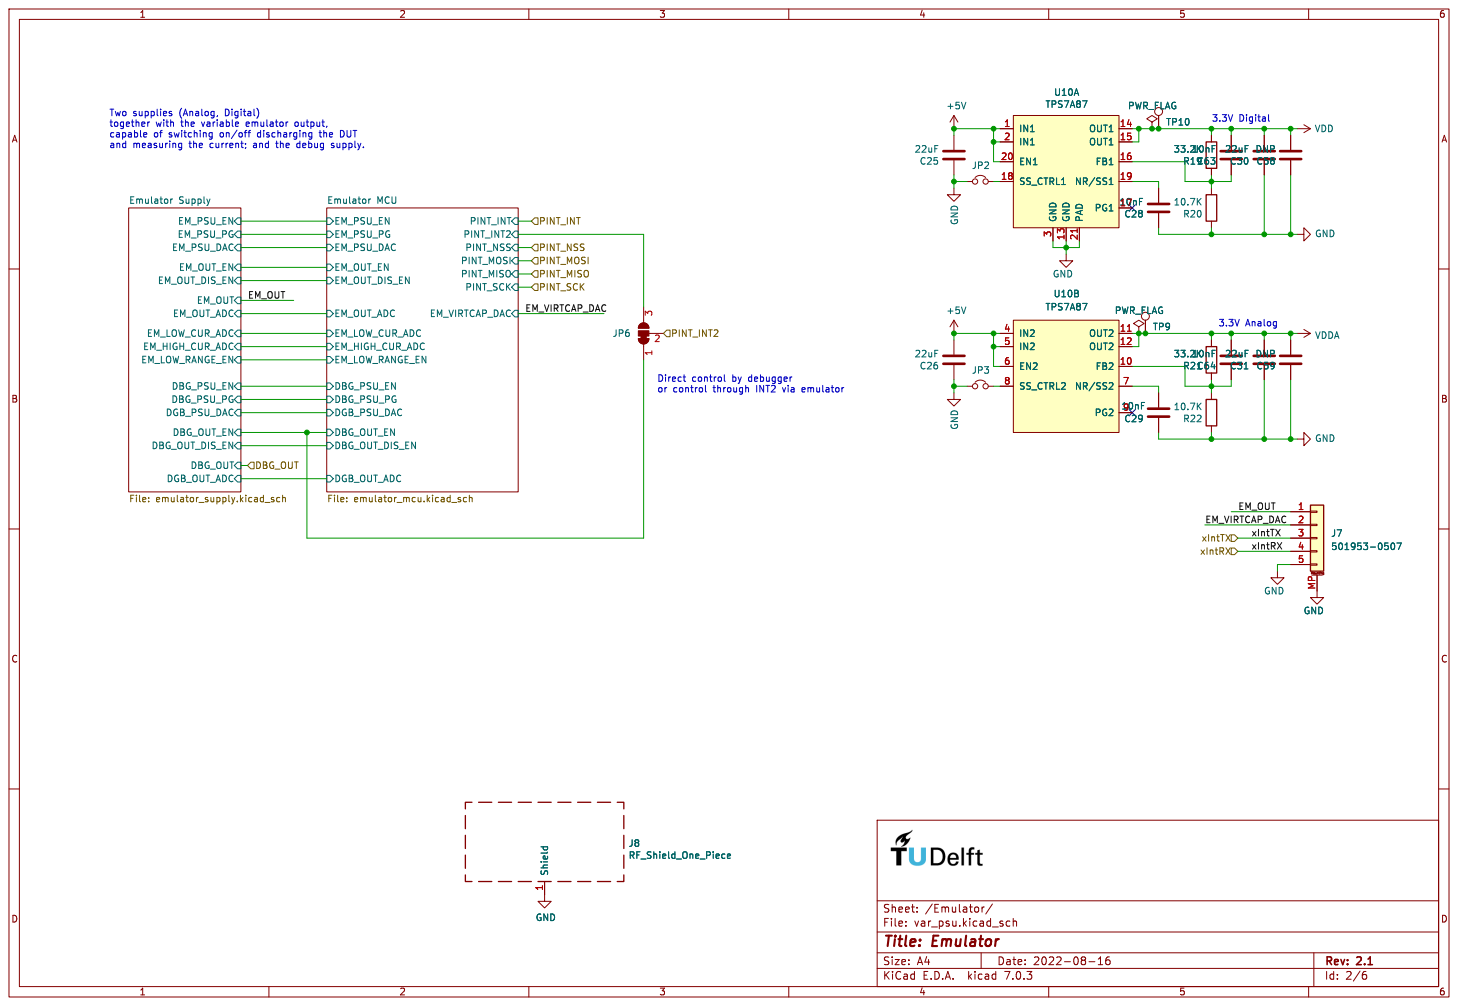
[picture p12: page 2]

Two supplies (Analog, Digital)

Id: 2/6 Title: Emulator File: var_psu.kicad_sch Sheet: /Emulator/

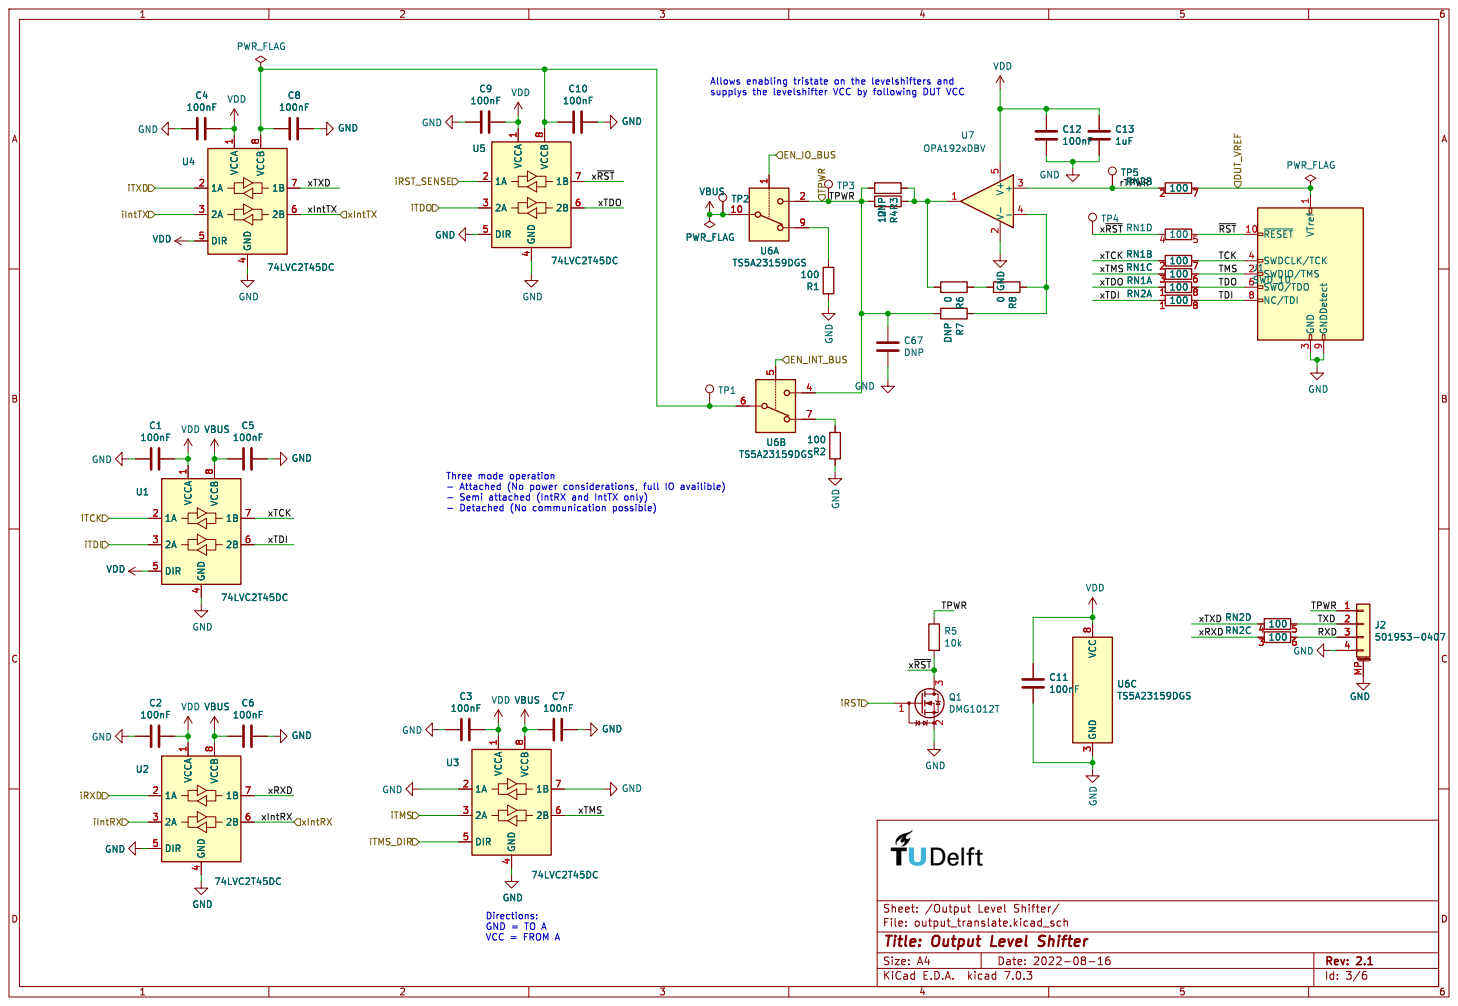
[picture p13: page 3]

3 SWDCLK/TCK 4 SWO/TDO 6 NC/TDI 8 GNDDetect 9

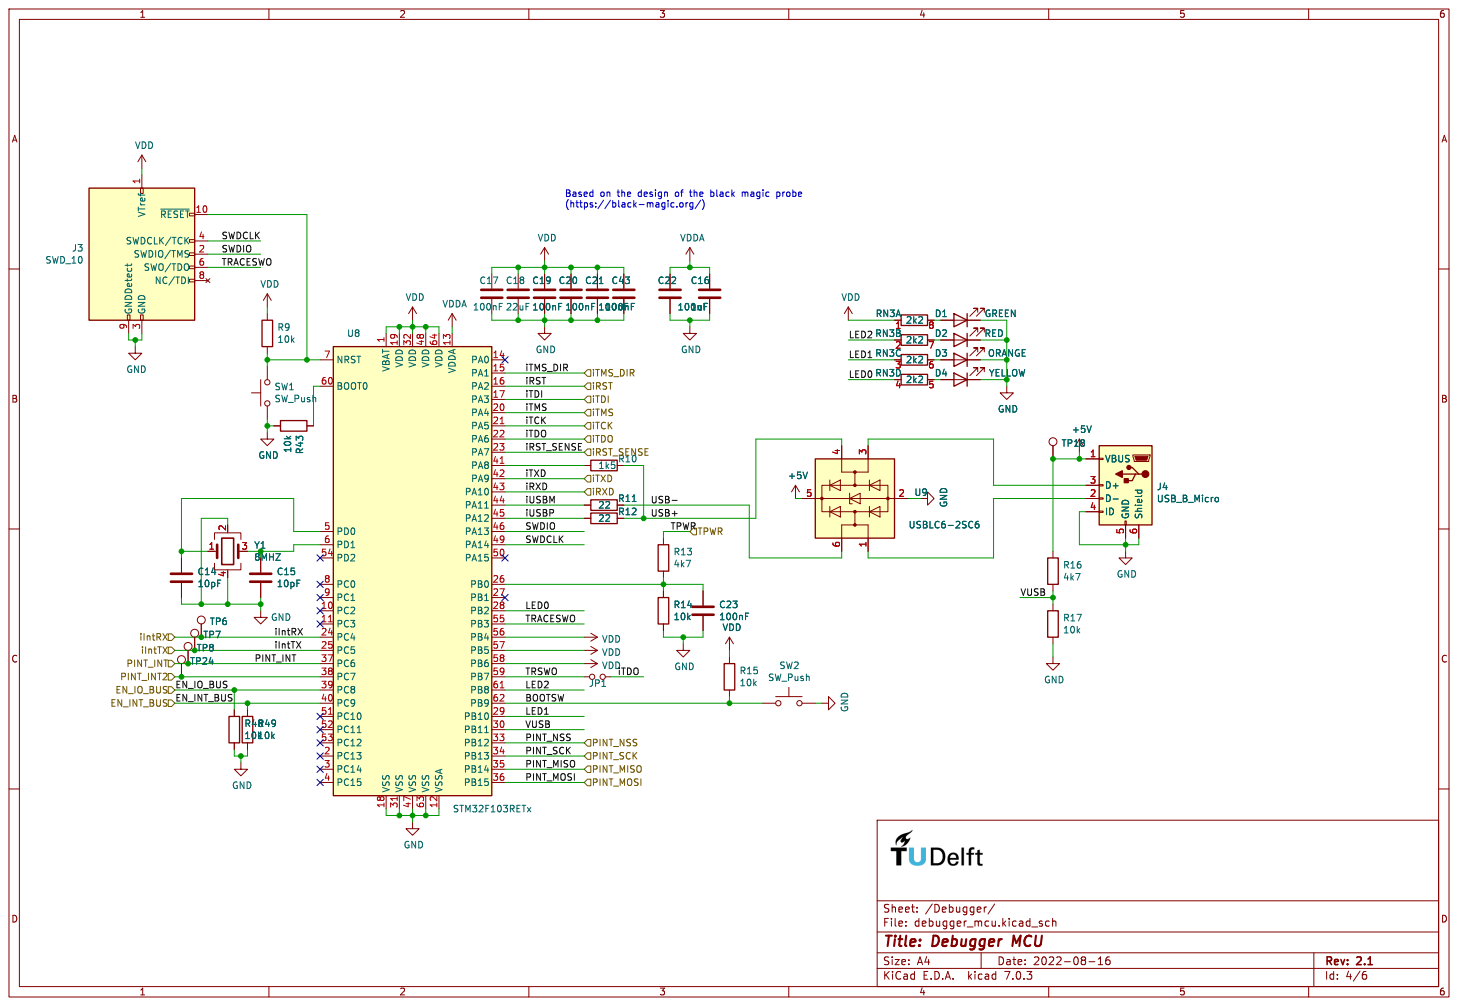
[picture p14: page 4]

Based on the design of the black magic probe
(https://black-magic.org/) R11

3 SWDCLK/TCK 4 SWO/TDO 6 NC/TDI 8 GNDDetect 9

1 PC2 10 PC3 11 VSSA 12 VDDA 13 PA0 14 PA1 15 PA2 16 PA3 17 VSS 18 VDD 19 PC13 2 PA4 20 PA5 21 PA6 22 PA7 23 PC4 24 PC5 25 PB0 26 PB1 27 PB2 28 PB10 29 PC14 3 PB11 30 VSS 31 VDD 32 PB12 33 PB13 34 PB14 35 PB15 36 PC6 37 PC7 38 PC8 39 PC15 4 PC9 40 PA8 41 PA9 42 PA10 43 PA11 44 PA12 45 PA13 46 VSS 47 VDD 48 PA14 49 PD0 5 PA15 50 PC10 51 PC11 52 PC12 53 PD2 54 PB3 55 PB4 56 PB5 57 PB6 58 PB7 59 PD1 6 BOOT0 60 PB8 61 PB9 62 VSS 63 VDD 64 NRST 7 PC0 8 PC1 9 U8 STM32F103RETx R12

File: debugger_mcu.kicad_sch Sheet: /Debugger/
Id: 4/6 Title: Debugger MCU

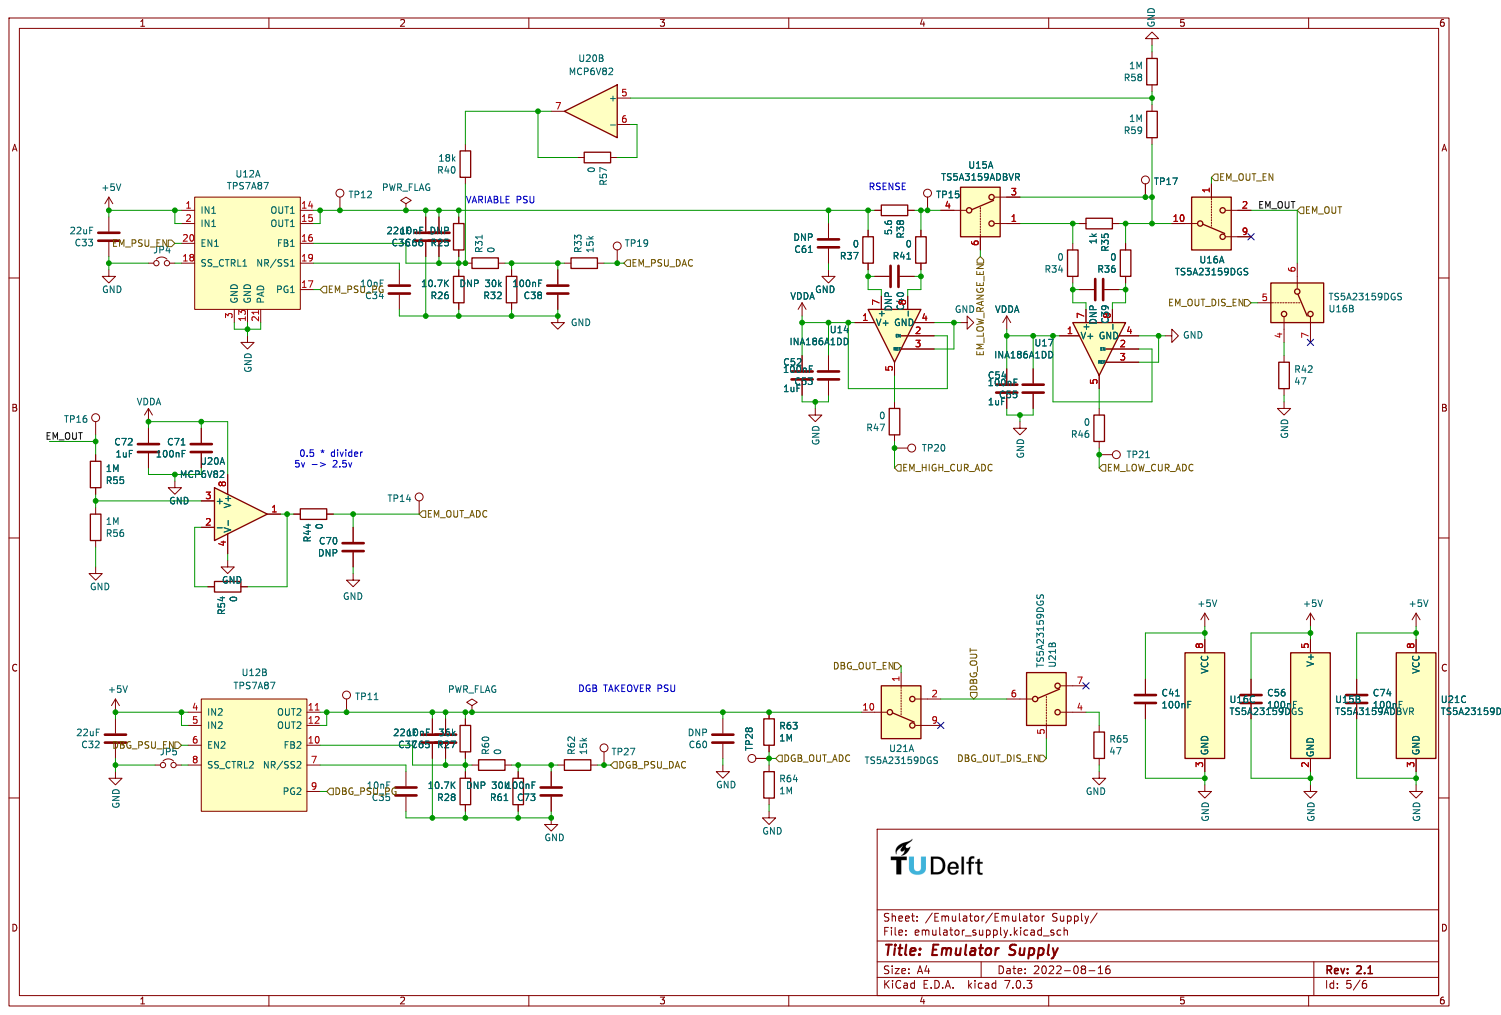
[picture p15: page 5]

Id: 5/6 Title: Emulator Supply

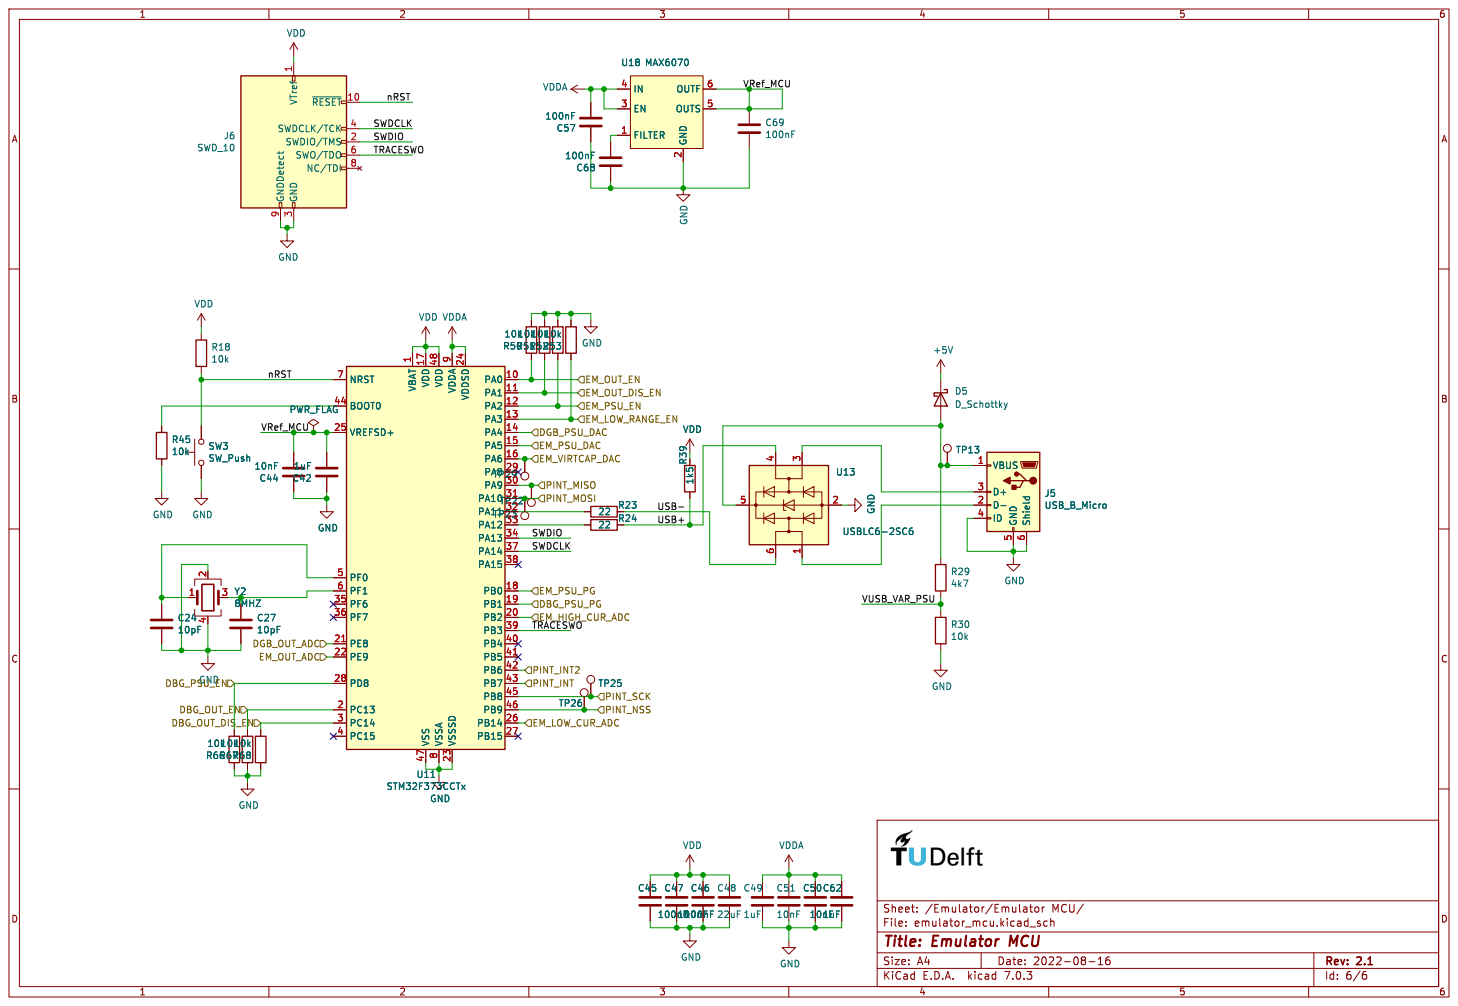
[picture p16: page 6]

Id: 6/6 Title: Emulator MCU

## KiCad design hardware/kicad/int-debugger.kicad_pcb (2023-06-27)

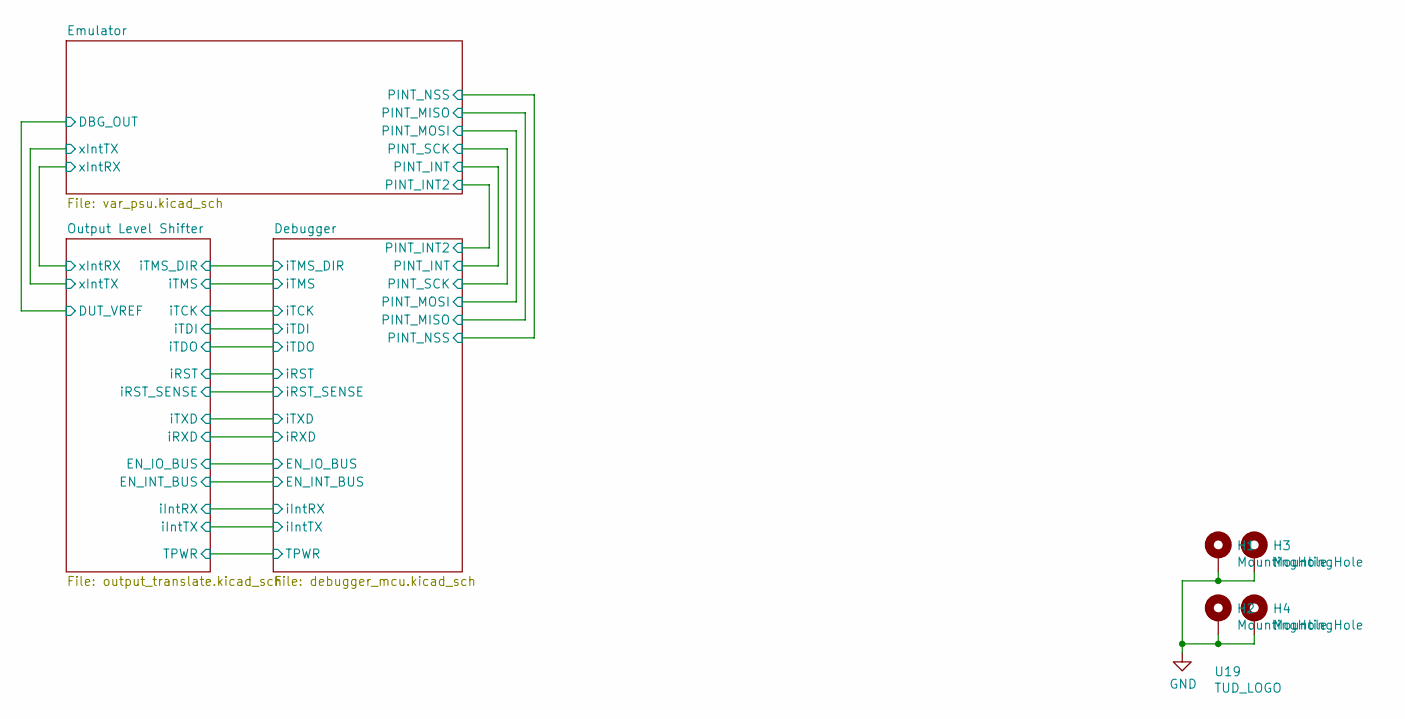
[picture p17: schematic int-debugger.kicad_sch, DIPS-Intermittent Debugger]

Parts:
H1, H2, H3, H4: MountingHole; MountingHole_2.2mm_M2_DIN965_Pad_TopBottom
U19: TUD_LOGO; DELFT_LOGO2

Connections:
GND: H1.1, H2.1, H3.1, H4.1; also elsewhere on the board

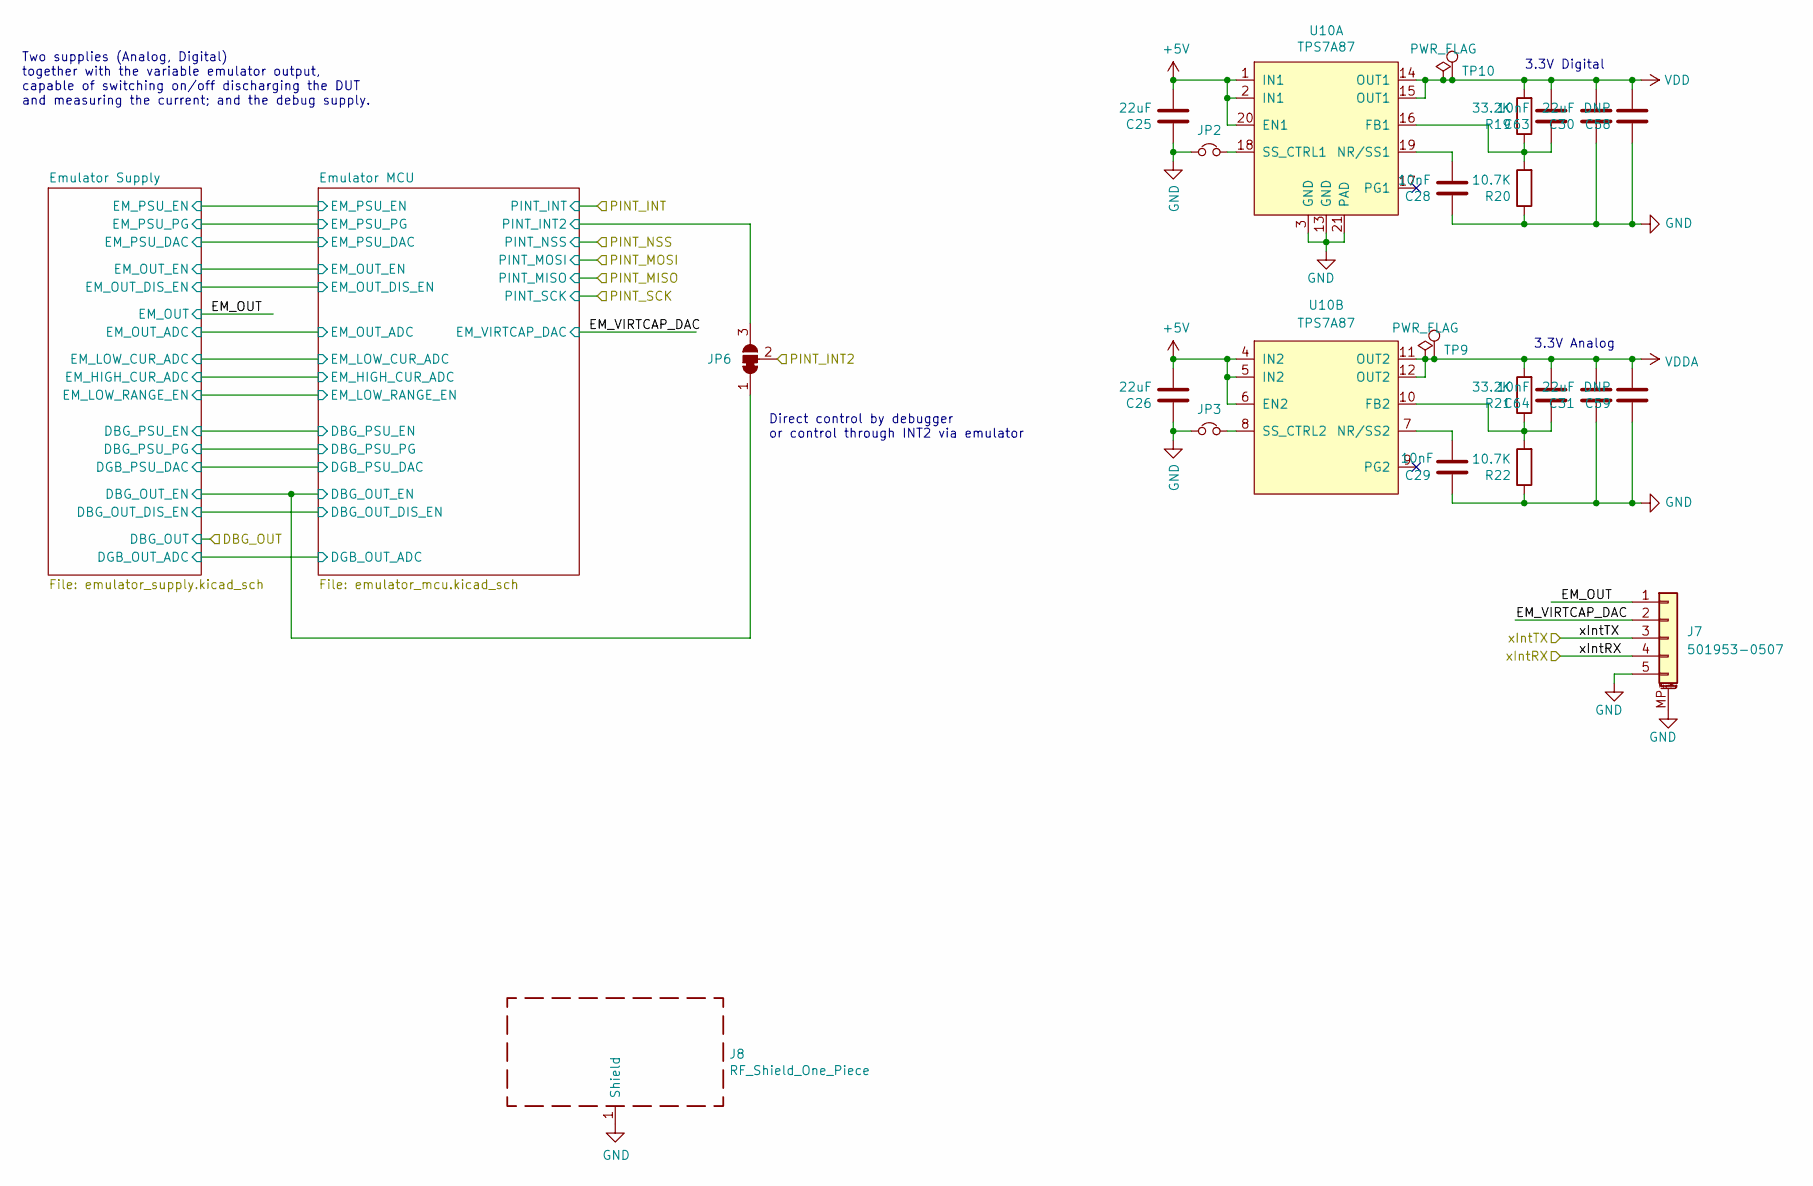
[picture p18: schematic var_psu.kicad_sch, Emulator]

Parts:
C25, C26, C30, C31: 22uF; C_0603_1608Metric; MPN GRM188R61A226ME15D
C28, C29, C63, C64: 10nF; C_0603_1608Metric; MPN 06035C103KAT2A
C58, C59: DNP; C_0603_1608Metric
J7: 501953-0507; Molex_Pico-Clasp_501953-0507_1x05-1MP_P1.00mm_Horizontal; MPN 501953-0507
J8: RF_Shield_One_Piece; Laird_Technologies_BMI-S-209-F_29.36x18.50mm; MPN BMI-S-209-F + BMI-S-209-C
JP2, JP3: Jumper_NC_Small; SolderJumper-small-nc
JP6: SolderJumper_3_Bridged12; SolderJumper-3_P1.3mm_Bridged12_Pad1.0x1.5mm
R19, R21: 33.2K; R_0603_1608Metric; MPN RC0603FR-0733K2L
R20, R22: 10.7K; R_0603_1608Metric; MPN RC0603FR-0710K7L
TP9, TP10: TestPoint; TestPoint_Keystone_5000-5004_Miniature
U10: TPS7A87; Texas-WQFN-20

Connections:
+5V: C25.2, C26.2, U10.1 (IN1), U10.2 (IN1), U10.4 (IN2), U10.5 (IN2), U10.6 (EN2), U10.20 (EN1); also elsewhere on the board
/Debugger/PINT_INT2: JP6.2 (C); also elsewhere on the board
/Emulator/EM_OUT: J7.1; also elsewhere on the board
/Emulator/EM_VIRTCAP_DAC: J7.2; also elsewhere on the board
/Emulator/Emulator MCU/DBG_OUT_EN: JP6.1 (A); also elsewhere on the board
/Emulator/Emulator MCU/PINT_INT2: JP6.3 (B); also elsewhere on the board
/Emulator/xIntRX: J7.4; also elsewhere on the board
/Emulator/xIntTX: J7.3; also elsewhere on the board
GND: C25.1, C26.1, C28.1, C29.1, C30.1, C31.1, C58.1, C59.1, J7.5, J7.MP (MountPin), J8.1 (Shield), JP2.1, JP3.1, R20.1, R22.1, U10.3 (GND), U10.13 (GND), U10.21 (PAD); also elsewhere on the board
unnamed: C63.1, R19.1, R20.2, U10.16 (FB1)
unnamed: C28.2, U10.19 (NR/SS1)
unnamed: JP2.2, U10.18 (SS_CTRL1)
unnamed: C64.1, R21.1, R22.2, U10.10 (FB2)
unnamed: C29.2, U10.7 (NR/SS2)
unnamed: JP3.2, U10.8 (SS_CTRL2)
VDD: C30.2, C58.2, C63.2, R19.2, TP10.1, U10.14 (OUT1), U10.15 (OUT1); also elsewhere on the board
VDDA: C31.2, C59.2, C64.2, R21.2, TP9.1, U10.11 (OUT2), U10.12 (OUT2); also elsewhere on the board

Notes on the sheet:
Direct control by debugger or control through INT2 via emulator
3.3V Digital
Two supplies (Analog, Digital) together with the variable emulator output, capable of switching on/off discharging the DUT and measuring the current; and the debug supply.
3.3V Analog

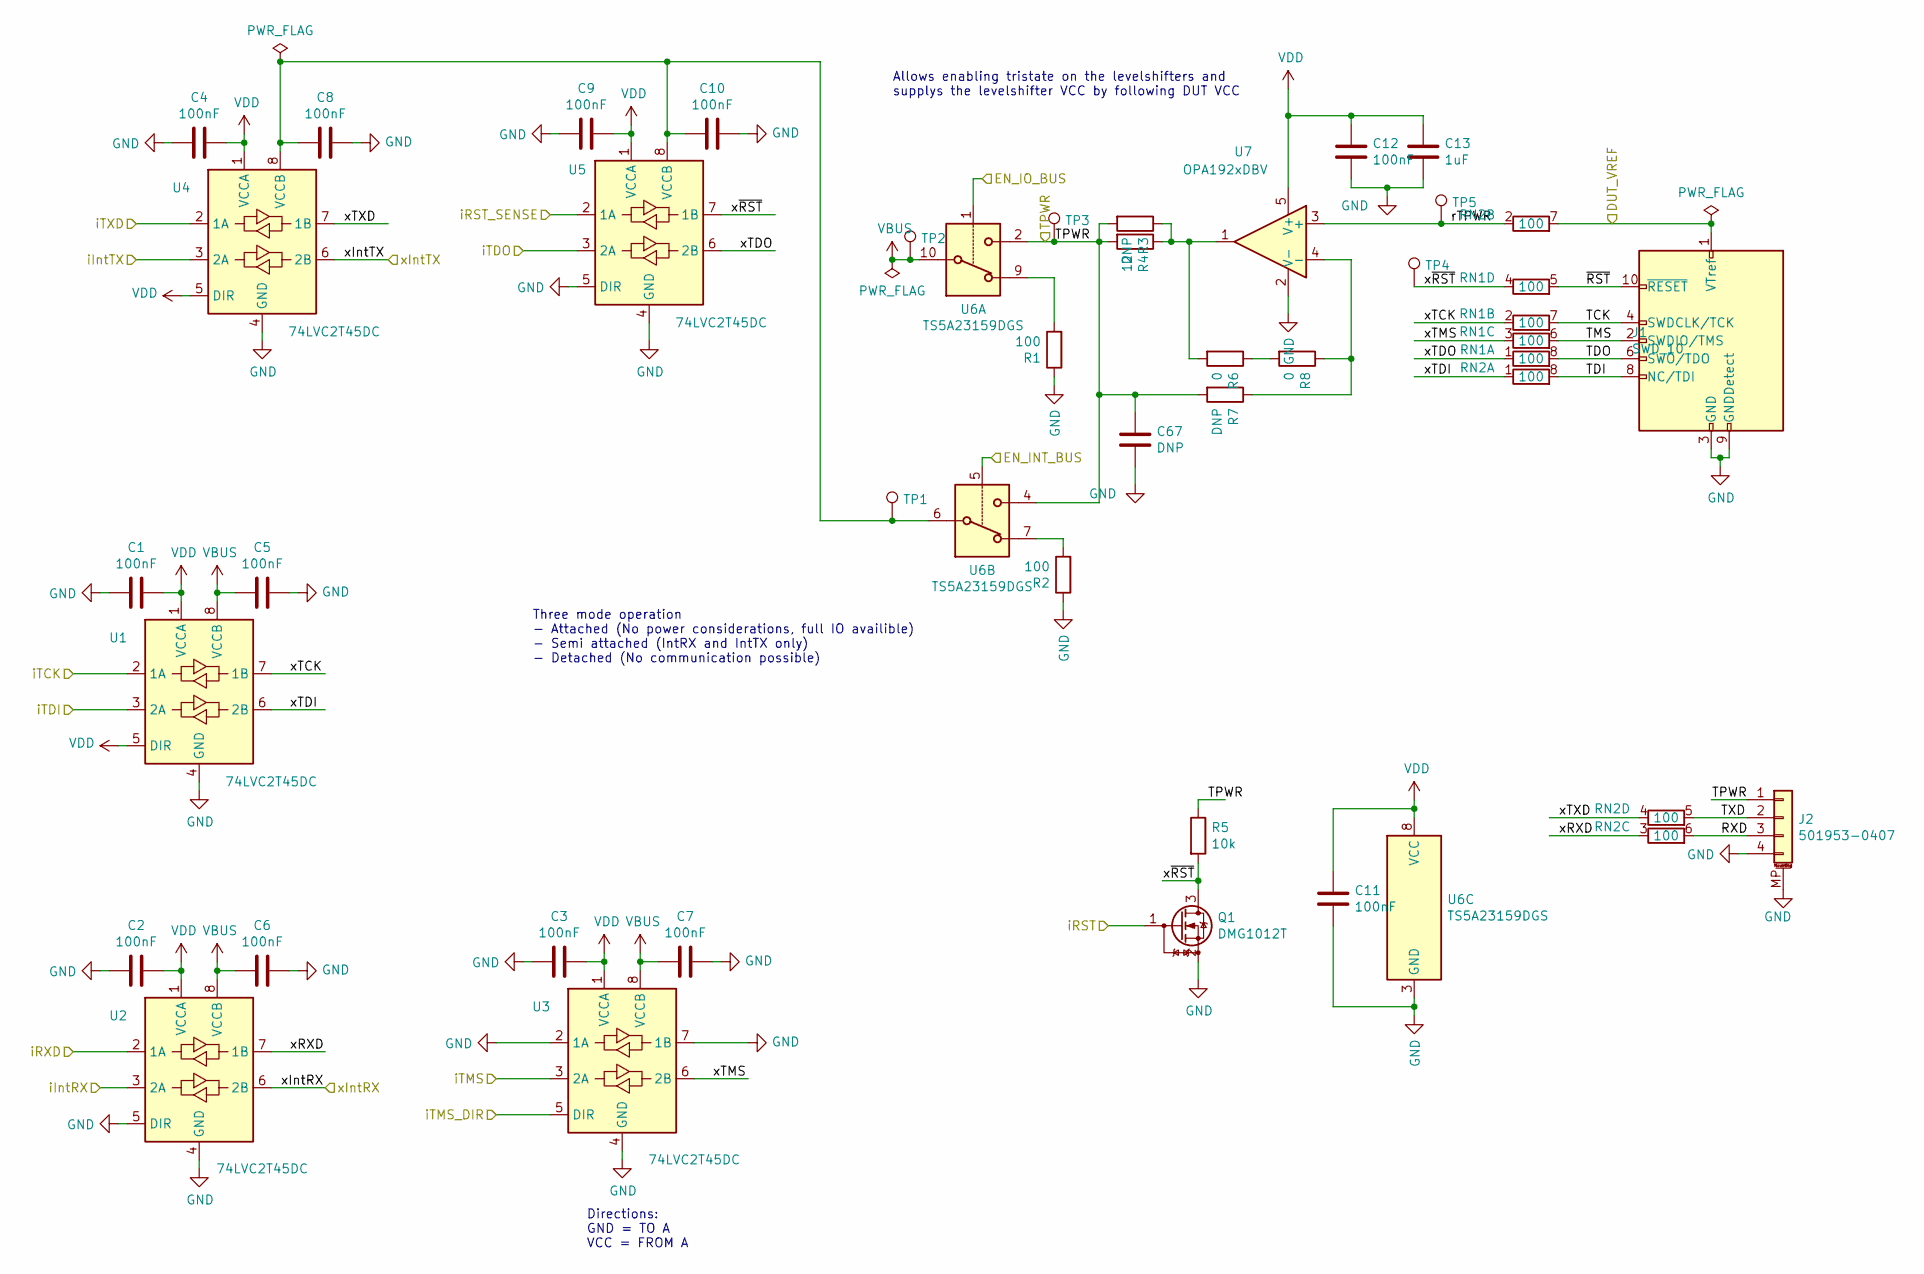
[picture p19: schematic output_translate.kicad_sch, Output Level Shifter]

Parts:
C1, C2, C3, C4, C5, C6, C7, C8, C9, C10, C11, C12: 100nF; C_0603_1608Metric; MPN CL10B104KB8NNNC
C13: 1uF; C_0603_1608Metric; MPN TMK107B7105KA-T
C67: DNP; C_0603_1608Metric
J1: SWD_10; FTSH-105-01-F-D-RA-K; MPN FTSH-105-01-F-D-RA-K
J2: 501953-0407; Molex_Pico-Clasp_501953-0407_1x04-1MP_P1.00mm_Horizontal; MPN 501953-0407
Q1: DMG1012T; SOT-523; MPN DMG1012T
R1, R2: 100; R_0603_1608Metric; MPN RC0603FR-07100RL
R3, R7: DNP; R_0603_1608Metric
R4: 12; R_0603_1608Metric; MPN RC0603FR-0712RL
R5: 10k; R_0603_1608Metric; MPN RC0603FR-0710KL
R6, R8: 0; R_0603_1608Metric; MPN RC0603FR-070RL
RN1, RN2: 100; R_Array_Convex_4x1206; MPN YC324-JK-07100RL
TP1, TP2, TP3, TP4, TP5: TestPoint; TestPoint_Keystone_5000-5004_Miniature
U1, U2, U3, U4, U5: 74LVC2T45DC; VSSOP-8_2.3x2mm_P0.5mm; MPN 74LVC2T45DC
U6: TS5A23159DGS; VSSOP-10_3x3mm_P0.5mm; MPN TS5A23159DGS
U7: OPA192xDBV; SOT-23-5; MPN OPA192IDBV

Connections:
/Debugger/EN_INT_BUS: U6.5; also elsewhere on the board
/Debugger/EN_IO_BUS: U6.1; also elsewhere on the board
/Debugger/TPWR: C67.1, J2.1, R3.2, R4.2, R5.1, R7.2, TP3.1, U6.2, U6.4; also elsewhere on the board
/Debugger/iIntRX: U2.3 (2A); also elsewhere on the board
/Debugger/iIntTX: U4.3 (2A); also elsewhere on the board
/Debugger/iRST: Q1.1 (G); also elsewhere on the board
/Debugger/iRST_SENSE: U5.2 (1A); also elsewhere on the board
/Debugger/iRXD: U2.2 (1A); also elsewhere on the board
/Debugger/iTCK: U1.2 (1A); also elsewhere on the board
/Debugger/iTDI: U1.3 (2A); also elsewhere on the board
/Debugger/iTDO: U5.3 (2A); also elsewhere on the board
/Debugger/iTMS: U3.3 (2A); also elsewhere on the board
/Debugger/iTMS_DIR: U3.5 (DIR); also elsewhere on the board
/Debugger/iTXD: U4.2 (1A); also elsewhere on the board
/Emulator/DBG_OUT: J1.1 (VTref), RN2.7 (R2.2); also elsewhere on the board
/Emulator/xIntRX: U2.6 (2B); also elsewhere on the board
/Emulator/xIntTX: U4.6 (2B); also elsewhere on the board
/Output Level Shifter/RXD: J2.3, RN2.6 (R3.2)
/Output Level Shifter/TCK: J1.4 (SWDCLK/TCK), RN1.7 (R2.2)
/Output Level Shifter/TDI: J1.8 (NC/TDI), RN2.8 (R1.2)
/Output Level Shifter/TDO: J1.6 (SWO/TDO), RN1.8 (R1.2)
/Output Level Shifter/TMS: J1.2 (SWDIO/TMS), RN1.6 (R3.2)
/Output Level Shifter/TXD: J2.2, RN2.5 (R4.2)
/Output Level Shifter/rTPWR: RN2.2 (R2.1), TP5.1, U7.3 (+)
/Output Level Shifter/xRXD: RN2.3 (R3.1), U2.7 (1B)
/Output Level Shifter/xTCK: RN1.2 (R2.1), U1.7 (1B)
/Output Level Shifter/xTDI: RN2.1 (R1.1), U1.6 (2B)
/Output Level Shifter/xTDO: RN1.1 (R1.1), U5.6 (2B)
/Output Level Shifter/xTMS: RN1.3 (R3.1), U3.6 (2B)
/Output Level Shifter/xTXD: RN2.4 (R4.1), U4.7 (1B)
/Output Level Shifter/x~RST: Q1.3 (D), R5.2, RN1.4 (R4.1), TP4.1, U5.7 (1B)
/Output Level Shifter/~RST: J1.10 (~RESET), RN1.5 (R4.2)
GND: C1.2, C2.2, C3.2, C4.2, C5.1, C6.1, C7.1, C8.1, C9.2, C10.1, C11.2, C12.2, C13.2, C67.2, J1.3 (GND), J1.5 (GND), J1.9 (GNDDetect), J2.4, J2.MP (MountPin), Q1.2 (S), R1.1, R2.1, U1.4 (GND), U2.4 (GND), U2.5 (DIR), U3.2 (1A), U3.4 (GND), U3.7 (1B), U4.4 (GND), U5.4 (GND), U5.5 (DIR), U6.3 (GND), U7.2 (V-); also elsewhere on the board
unnamed: R1.2, U6.9
unnamed: R2.2, U6.7
unnamed: R3.1, R4.1, R6.2, U7.1
unnamed: R6.1, R8.2
unnamed: C8.2, C10.2, TP1.1, U4.8 (VCCB), U5.8 (VCCB), U6.6
unnamed: R7.1, R8.1, U7.4 (-)
VBUS: C5.2, C6.2, C7.2, TP2.1, U1.8 (VCCB), U2.8 (VCCB), U3.8 (VCCB), U6.10
VDD: C1.1, C2.1, C3.1, C4.1, C9.1, C11.1, C12.1, C13.1, U1.1 (VCCA), U1.5 (DIR), U2.1 (VCCA), U3.1 (VCCA), U4.1 (VCCA), U4.5 (DIR), U5.1 (VCCA), U6.8 (VCC), U7.5 (V+); also elsewhere on the board

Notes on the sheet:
Allows enabling tristate on the levelshifters and supplys the levelshifter VCC by following DUT VCC
Three mode operation - Attached (No power considerations, full IO availible) - Semi attached (IntRX and IntTX only) - Detached (No communication possible)
Directions: GND = TO A VCC = FROM A

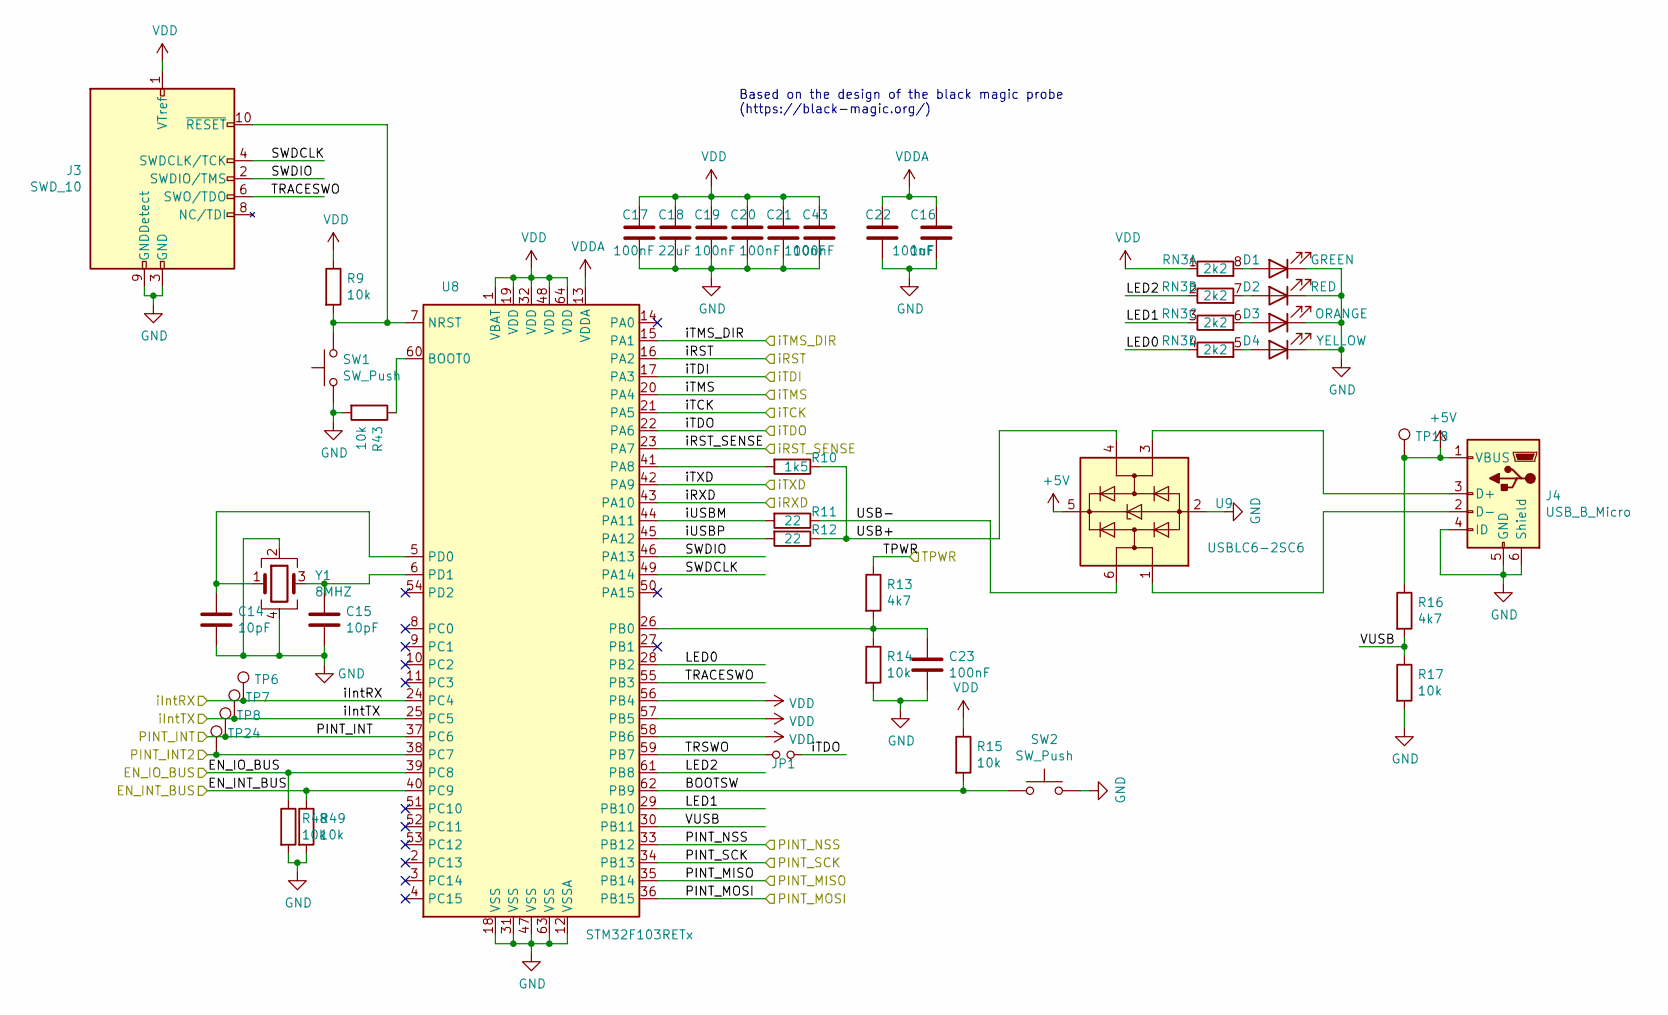
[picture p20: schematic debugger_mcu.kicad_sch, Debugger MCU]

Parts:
C14, C15: 10pF; C_0603_1608Metric; MPN CC0603CRNPO9BN100
C16: 1uF; C_0603_1608Metric; MPN TMK107B7105KA-T
C17, C19, C20, C21, C22, C23, C43: 100nF; C_0603_1608Metric; MPN CL10B104KB8NNNC
C18: 22uF; C_0603_1608Metric; MPN GRM188R61A226ME15D
D1: GREEN; LED_0603_1608Metric; MPN LTST-C190KGKT
D2: RED; LED_0603_1608Metric; MPN LTST-C193KRKT-5A
D3: ORANGE; LED_0603_1608Metric; MPN APT1608LSECK/J4-PRV
D4: YELLOW; LED_0603_1608Metric; MPN APTD1608LSYCK/J3-PF
J3: SWD_10; ftsh-105-01-f-dv-k; MPN ftsh-105-01-f-dv-k
J4: USB_B_Micro; USB_Micro-B_Molex-105017-0001; MPN 105017-0001
JP1: Jumper_NO_Small; SolderJumper-small-no-150um
R9, R14, R15, R17, R43, R48, R49: 10k; R_0603_1608Metric; MPN RC0603FR-0710KL
R10: 1k5; R_0603_1608Metric; MPN RC0603FR-071K5L
R11, R12: 22; R_0603_1608Metric; MPN RC0603FR-0722RL
R13, R16: 4k7; R_0603_1608Metric; MPN RC0603FR-074K7L
RN3: 2k2; R_Array_Convex_4x1206; MPN YC324-JK-072K2L
SW1, SW2: SW_Push; SW_SPST_B3U-1000P; MPN B3U-1000P
TP6, TP7, TP8, TP18, TP24: TestPoint; TestPoint_Keystone_5000-5004_Miniature
U8: STM32F103RETx; LQFP-64_10x10mm_P0.5mm; MPN STM32F103RET
U9: USBLC6-2SC6; SOT-23-6; MPN USBLC6-2SC6
Y1: 8MHZ; Crystal_SMD_Abracon_ABM3B-4Pin_5.0x3.2mm; MPN ABM3B-8.000MHZ-10-D-1-G-T

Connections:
+5V: J4.1 (VBUS), R16.1, TP18.1, U9.5 (VBUS); also elsewhere on the board
/Debugger/BOOTSW: R15.2, SW2.1, U8.62 (PB9)
/Debugger/EN_INT_BUS: R49.1, U8.40 (PC9); also elsewhere on the board
/Debugger/EN_IO_BUS: R48.1, U8.39 (PC8); also elsewhere on the board
/Debugger/LED0: RN3.4 (R4.1), U8.28 (PB2)
/Debugger/LED1: RN3.3 (R3.1), U8.29 (PB10)
/Debugger/LED2: RN3.2 (R2.1), U8.61 (PB8)
/Debugger/PINT_INT: TP8.1, U8.37 (PC6); also elsewhere on the board
/Debugger/PINT_INT2: TP24.1, U8.38 (PC7); also elsewhere on the board
/Debugger/PINT_MISO: U8.35 (PB14); also elsewhere on the board
/Debugger/PINT_MOSI: U8.36 (PB15); also elsewhere on the board
/Debugger/PINT_NSS: U8.33 (PB12); also elsewhere on the board
/Debugger/PINT_SCK: U8.34 (PB13); also elsewhere on the board
/Debugger/SWDCLK: J3.4 (SWDCLK/TCK), U8.49 (PA14)
/Debugger/SWDIO: J3.2 (SWDIO/TMS), U8.46 (PA13)
/Debugger/TPWR: R13.1; also elsewhere on the board
/Debugger/TRACESWO: J3.6 (SWO/TDO), U8.55 (PB3)
/Debugger/TRSWO: JP1.1, U8.59 (PB7)
/Debugger/USB+: R10.1, R12.1, U9.4 (I/O2)
/Debugger/USB-: R11.1, U9.6 (I/O1)
/Debugger/VUSB: R16.2, R17.1, U8.30 (PB11)
/Debugger/iIntRX: TP6.1, U8.24 (PC4); also elsewhere on the board
/Debugger/iIntTX: TP7.1, U8.25 (PC5); also elsewhere on the board
/Debugger/iRST: U8.16 (PA2); also elsewhere on the board
/Debugger/iRST_SENSE: U8.23 (PA7); also elsewhere on the board
/Debugger/iRXD: U8.43 (PA10); also elsewhere on the board
/Debugger/iTCK: U8.21 (PA5); also elsewhere on the board
/Debugger/iTDI: U8.17 (PA3); also elsewhere on the board
/Debugger/iTDO: JP1.2, U8.22 (PA6); also elsewhere on the board
/Debugger/iTMS: U8.20 (PA4); also elsewhere on the board
/Debugger/iTMS_DIR: U8.15 (PA1); also elsewhere on the board
/Debugger/iTXD: U8.42 (PA9); also elsewhere on the board
/Debugger/iUSBM: R11.2, U8.44 (PA11)
/Debugger/iUSBP: R12.2, U8.45 (PA12)
GND: C14.2, C15.2, C16.2, C17.2, C18.2, C19.2, C20.2, C21.2, C22.2, C23.2, C43.2, D1.1 (K), D2.1 (K), D3.1 (K), D4.1 (K), J3.3 (GND), J3.5 (GND), J3.9 (GNDDetect), J4.4 (ID), J4.5 (GND), J4.6 (Shield), R14.2, R17.2, R43.2, R48.2, R49.2, SW1.1, SW2.2, U8.12 (VSSA), U8.18 (VSS), U8.31 (VSS), U8.47 (VSS), U8.63 (VSS), U9.2 (GND), Y1.2, Y1.4; also elsewhere on the board
unnamed: D1.2 (A), RN3.8 (R1.2)
unnamed: D2.2 (A), RN3.7 (R2.2)
unnamed: D3.2 (A), RN3.6 (R3.2)
unnamed: D4.2 (A), RN3.5 (R4.2)
unnamed: J3.10 (~RESET), R9.2, SW1.2, U8.7 (NRST)
unnamed: J4.3 (D+), U9.3 (I/O2)
unnamed: J4.2 (D-), U9.1 (I/O1)
unnamed: R43.1, U8.60 (BOOT0)
unnamed: R10.2, U8.41 (PA8)
unnamed: C23.1, R13.2, R14.1, U8.26 (PB0)
unnamed: C14.1, U8.5 (PD0), Y1.1
unnamed: C15.1, U8.6 (PD1), Y1.3
VDD: C17.1, C18.1, C19.1, C20.1, C21.1, C43.1, J3.1 (VTref), R9.1, R15.1, RN3.1 (R1.1), U8.1 (VBAT), U8.19 (VDD), U8.32 (VDD), U8.48 (VDD), U8.56 (PB4), U8.57 (PB5), U8.58 (PB6), U8.64 (VDD); also elsewhere on the board
VDDA: C16.1, C22.1, U8.13 (VDDA); also elsewhere on the board

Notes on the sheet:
Based on the design of the black magic probe (https://black-magic.org/)

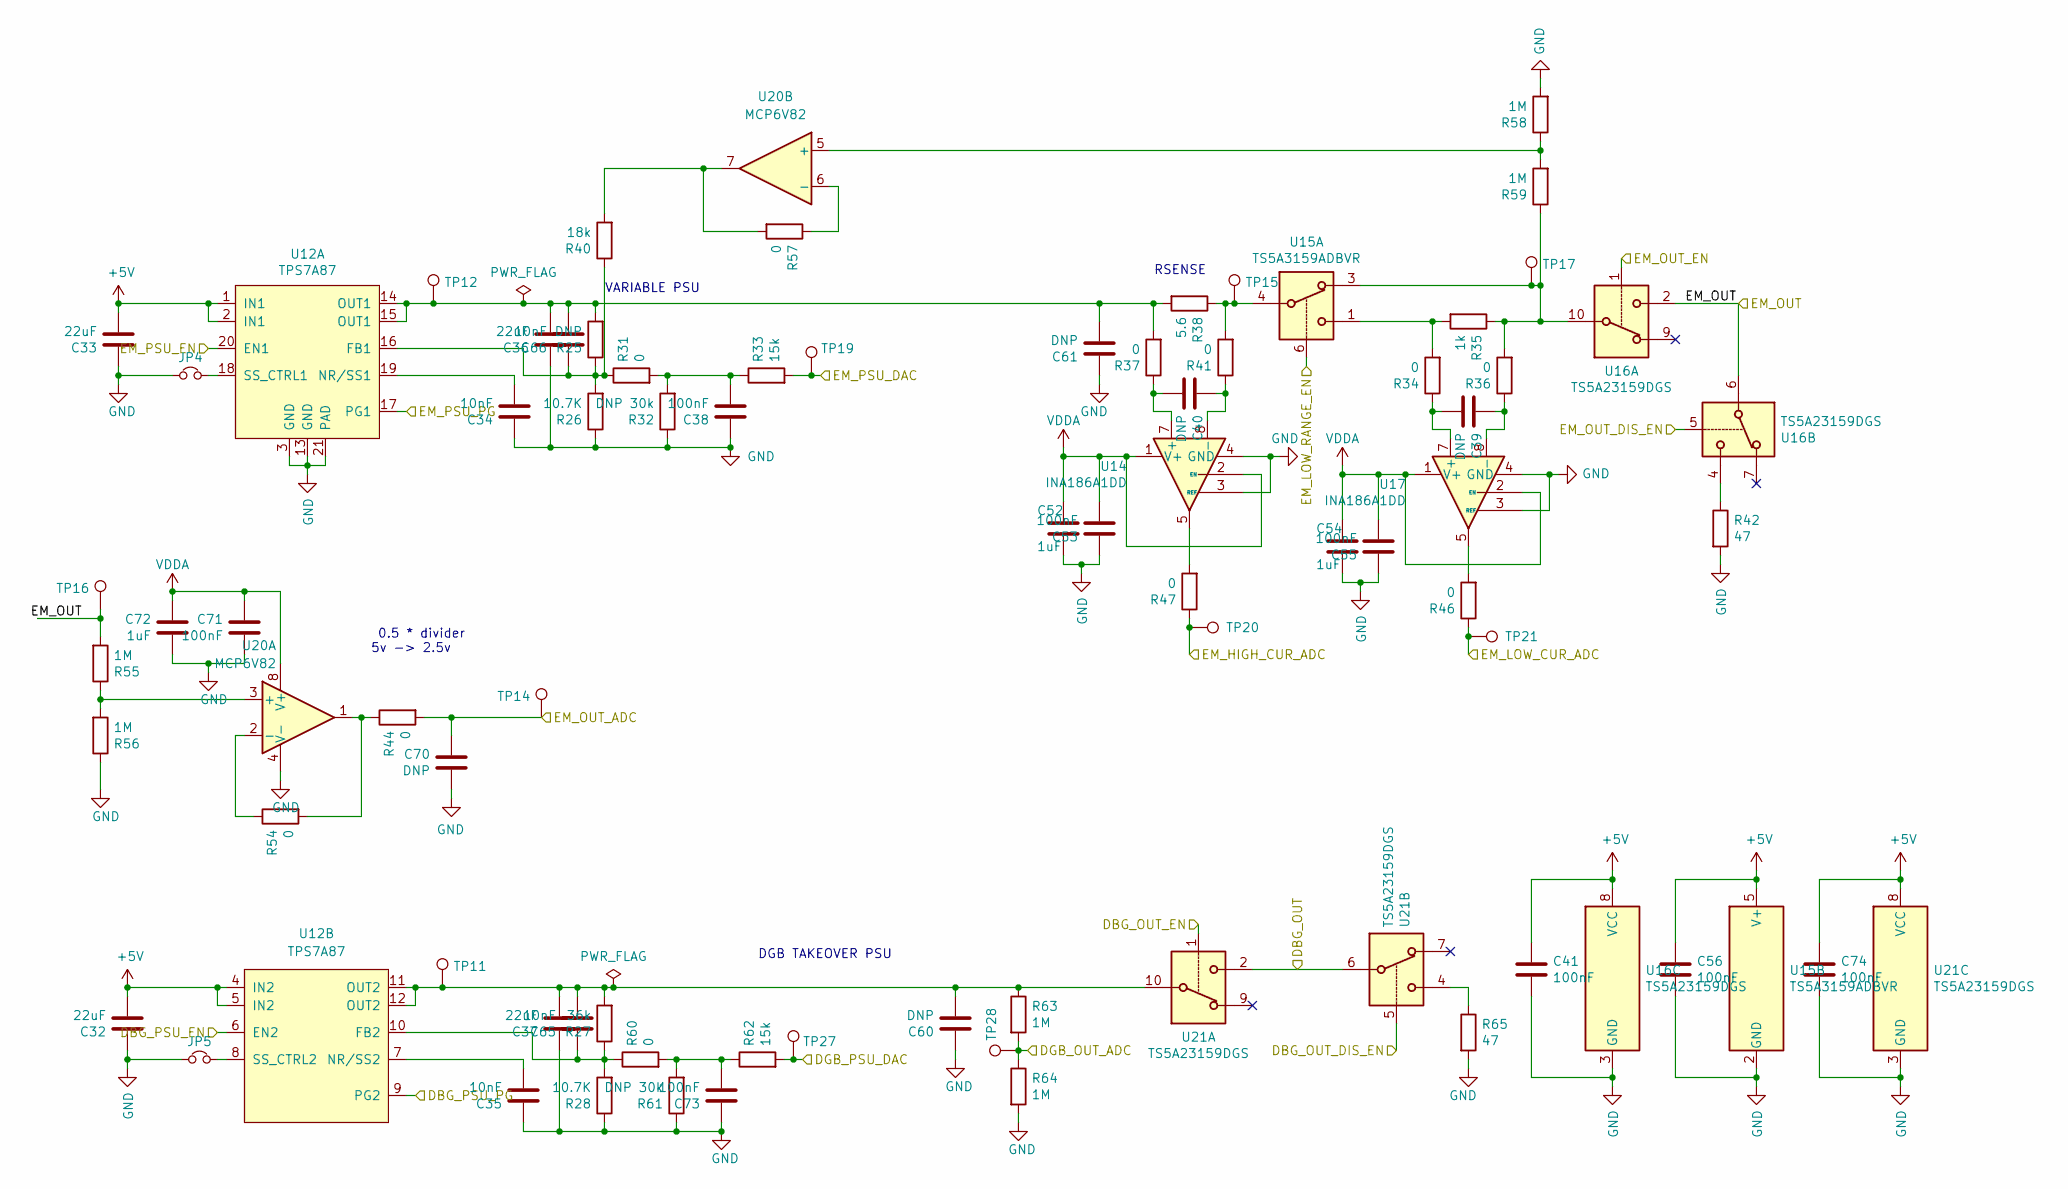
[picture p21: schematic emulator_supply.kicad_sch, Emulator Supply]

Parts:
C32, C33, C36, C37: 22uF; C_0603_1608Metric; MPN GRM188R61A226ME15D
C34, C35, C65, C66: 10nF; C_0603_1608Metric; MPN 06035C103KAT2A
C38, C41, C53, C55, C56, C71, C73, C74: 100nF; C_0603_1608Metric; MPN CL10B104KB8NNNC
C39, C40, C60, C61, C70: DNP; C_0603_1608Metric
C52, C54, C72: 1uF; C_0603_1608Metric; MPN TMK107B7105KA-T
JP4, JP5: Jumper_NC_Small; SolderJumper-small-nc
R25: DNP; R_0603_1608Metric
R26, R28: 10.7K; R_0603_1608Metric; MPN RC0603FR-0710K7L
R27: 36k; R_0603_1608Metric; MPN RC0603FR-0736KL
R31, R34, R36, R37, R41, R44, R46, R47, R54, R57, R60: 0; R_0603_1608Metric; MPN RC0603FR-070RL
R32, R61: DNP 30k; R_0603_1608Metric; MPN RC0603FR-0730KL
R33, R62: 15k; R_0603_1608Metric; MPN RC0603FR-0715KL
R35: 1k; R_0603_1608Metric; MPN MCWF06R1001BTL
R38: 5.6; R_0603_1608Metric; MPN ERJ3BQF5R6V
R40: 18k; R_0603_1608Metric; MPN RC0603FR-0718KL
R42, R65: 47; R_1206_3216Metric; MPN RC1206FR-7W47RL
R55, R56, R58, R59, R63, R64: 1M; R_0603_1608Metric; MPN MC008457
TP11, TP12, TP15, TP16, TP17: TestPoint; TestPoint_Keystone_5000-5004_Miniature
TP14, TP19, TP20, TP21, TP27, TP28: S2761-46R; MPN S2761-46R
U12: TPS7A87; Texas-WQFN-20
U14, U17: INA186A1DD; SOT-23-8; MPN INA186A1IDDF
U15: TS5A3159ADBVR; SOT-23-6; MPN TS5A3159ADBVR
U16, U21: TS5A23159DGS; VSSOP-10_3x3mm_P0.5mm; MPN TS5A23159DGS
U20: MCP6V82; MSOP-8_3x3mm_P0.65mm; MPN MCP6V82-E/MS

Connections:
+5V: C32.2, C33.2, C41.1, C56.1, C74.1, U12.1 (IN1), U12.2 (IN1), U12.4 (IN2), U12.5 (IN2), U15.5 (V+), U16.8 (VCC), U21.8 (VCC); also elsewhere on the board
/Emulator/DBG_OUT: U21.2, U21.6; also elsewhere on the board
/Emulator/EM_OUT: R55.2, TP16.1, U16.2, U16.6; also elsewhere on the board
/Emulator/Emulator MCU/DBG_OUT_DIS_EN: U21.5; also elsewhere on the board
/Emulator/Emulator MCU/DBG_OUT_EN: U21.1; also elsewhere on the board
/Emulator/Emulator MCU/DBG_PSU_EN: U12.6 (EN2); also elsewhere on the board
/Emulator/Emulator MCU/DBG_PSU_PG: U12.9 (PG2); also elsewhere on the board
/Emulator/Emulator MCU/DGB_OUT_ADC: R63.2, R64.1, TP28.1; also elsewhere on the board
/Emulator/Emulator MCU/DGB_PSU_DAC: R62.2, TP27.1; also elsewhere on the board
/Emulator/Emulator MCU/EM_HIGH_CUR_ADC: R47.1, TP20.1; also elsewhere on the board
/Emulator/Emulator MCU/EM_LOW_CUR_ADC: R46.1, TP21.1; also elsewhere on the board
/Emulator/Emulator MCU/EM_LOW_RANGE_EN: U15.6; also elsewhere on the board
/Emulator/Emulator MCU/EM_OUT_ADC: C70.1, R44.2, TP14.1; also elsewhere on the board
/Emulator/Emulator MCU/EM_OUT_DIS_EN: U16.5; also elsewhere on the board
/Emulator/Emulator MCU/EM_OUT_EN: U16.1; also elsewhere on the board
/Emulator/Emulator MCU/EM_PSU_DAC: R33.2, TP19.1; also elsewhere on the board
/Emulator/Emulator MCU/EM_PSU_EN: U12.20 (EN1); also elsewhere on the board
/Emulator/Emulator MCU/EM_PSU_PG: U12.17 (PG1); also elsewhere on the board
GND: C32.1, C33.1, C34.1, C35.1, C36.1, C37.1, C38.1, C41.2, C52.2, C53.1, C54.2, C55.1, C56.2, C60.1, C61.1, C70.2, C71.2, C72.2, C73.1, C74.2, JP4.1, JP5.1, R26.1, R28.1, R32.1, R42.2, R56.1, R58.2, R61.1, R64.2, R65.2, U12.3 (GND), U12.13 (GND), U12.21 (PAD), U14.3 (REF), U14.4 (GND), U15.2 (GND), U16.3 (GND), U17.3 (REF), U17.4 (GND), U20.4 (V-), U21.3 (GND); also elsewhere on the board
unnamed: C36.2, C61.2, C66.2, R25.2, R37.2, R38.2, TP12.1, U12.14 (OUT1), U12.15 (OUT1)
unnamed: C37.2, C60.2, C65.2, R27.2, R63.1, TP11.1, U12.11 (OUT2), U12.12 (OUT2), U21.10
unnamed: C38.2, R31.2, R32.2, R33.1
unnamed: C73.2, R60.2, R61.2, R62.1
unnamed: R34.2, R35.2, U15.1
unnamed: R35.1, R36.2, R59.1, TP17.1, U15.3, U16.10
unnamed: R38.1, R41.2, TP15.1, U15.4
unnamed: R40.2, R57.2, U20.7
unnamed: R42.1, U16.4
unnamed: R44.1, R54.2, U20.1
unnamed: R46.2, U17.5
unnamed: R47.2, U14.5
unnamed: R65.1, U21.4
unnamed: C66.1, R25.1, R26.2, R31.1, R40.1, U12.16 (FB1)
unnamed: C34.2, U12.19 (NR/SS1)
unnamed: JP4.2, U12.18 (SS_CTRL1)
unnamed: C65.1, R27.1, R28.2, R60.1, U12.10 (FB2)
unnamed: C35.2, U12.7 (NR/SS2)
unnamed: JP5.2, U12.8 (SS_CTRL2)
unnamed: C40.2, R37.1, U14.7 (+)
unnamed: C40.1, R41.1, U14.8 (-)
unnamed: C39.2, R34.1, U17.7 (+)
unnamed: C39.1, R36.1, U17.8 (-)
unnamed: R55.1, R56.2, U20.3 (+)
unnamed: R54.1, U20.2 (-)
unnamed: R58.1, R59.2, U20.5 (+)
unnamed: R57.1, U20.6 (-)
VDDA: C52.1, C53.2, C54.1, C55.2, C71.1, C72.1, U14.1 (V+), U14.2 (EN), U17.1 (V+), U17.2 (EN), U20.8 (V+); also elsewhere on the board

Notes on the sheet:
0.5 * divider 5v -> 2.5v
DGB TAKEOVER PSU
VARIABLE PSU
RSENSE

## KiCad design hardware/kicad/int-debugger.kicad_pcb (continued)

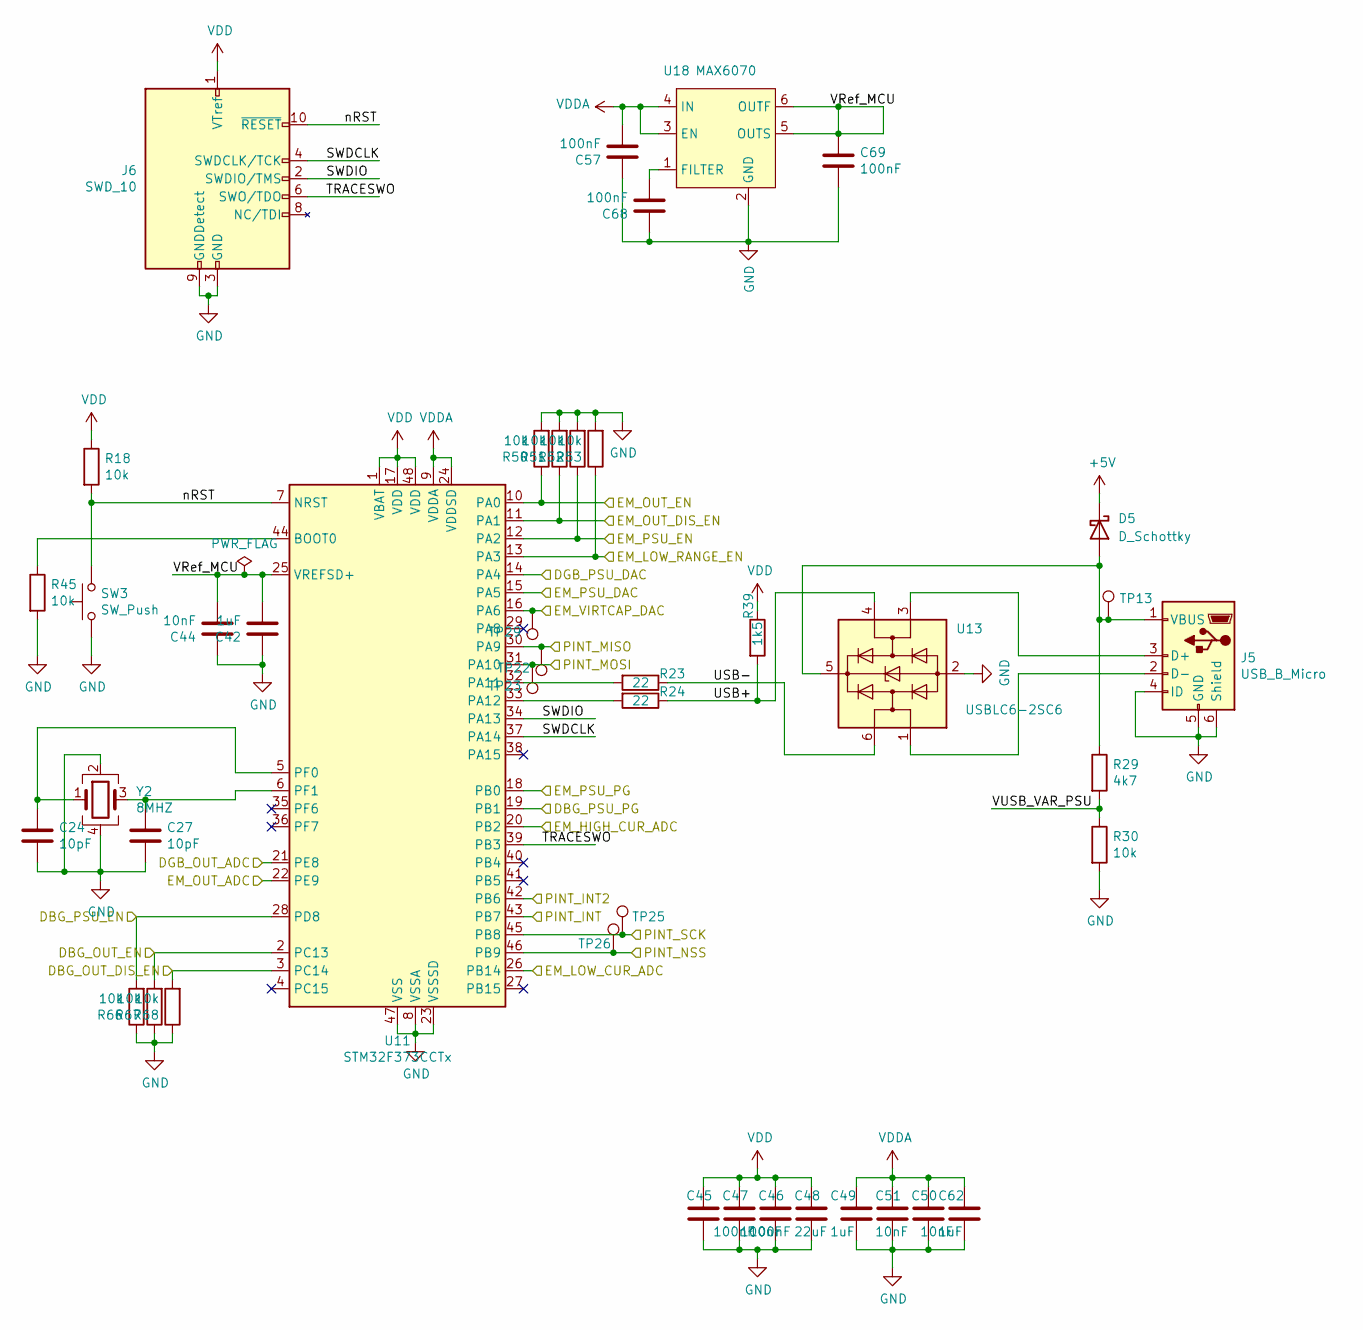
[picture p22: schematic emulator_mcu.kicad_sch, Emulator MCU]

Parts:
C24, C27: 10pF; C_0603_1608Metric; MPN CC0603CRNPO9BN100
C42, C49, C62: 1uF; C_0603_1608Metric; MPN TMK107B7105KA-T
C44, C50, C51: 10nF; C_0603_1608Metric; MPN 06035C103KAT2A
C45, C46, C47, C57, C68, C69: 100nF; C_0603_1608Metric; MPN CL10B104KB8NNNC
C48: 22uF; C_0603_1608Metric; MPN GRM188R61A226ME15D
D5: D_Schottky; D_SOD-323F; MPN PMEG6002EJ,115
J5: USB_B_Micro; USB_Micro-B_Molex-105017-0001; MPN 105017-0001
J6: SWD_10; ftsh-105-01-f-dv-k; MPN ftsh-105-01-f-dv-k
R18, R30, R45, R50, R51, R52, R53, R66, R67, R68: 10k; R_0603_1608Metric; MPN RC0603FR-0710KL
R23, R24: 22; R_0603_1608Metric; MPN RC0603FR-0722RL
R29: 4k7; R_0603_1608Metric; MPN RC0603FR-074K7L
R39: 1k5; R_0603_1608Metric; MPN RC0603FR-071K5L
SW3: SW_Push; SW_SPST_B3U-1000P; MPN B3U-1000P
TP13: TestPoint; TestPoint_Keystone_5000-5004_Miniature
TP22, TP23, TP25, TP26, TP29: S2761-46R; MPN S2761-46R
U11: STM32F373CCTx; LQFP-48_7x7mm_P0.5mm; MPN STM32F373CCT
U13: USBLC6-2SC6; SOT-23-6; MPN USBLC6-2SC6
U18: MAX6070; SOT-23-6; MPN MAX6070AAUT30+T
Y2: 8MHZ; Crystal_SMD_Abracon_ABM3B-4Pin_5.0x3.2mm; MPN ABM3B-8.000MHZ-10-D-1-G-T

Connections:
+5V: D5.1 (K); also elsewhere on the board
/Debugger/PINT_INT: U11.43 (PB7); also elsewhere on the board
/Debugger/PINT_MISO: TP22.1, U11.30 (PA9); also elsewhere on the board
/Debugger/PINT_MOSI: TP23.1, U11.31 (PA10); also elsewhere on the board
/Debugger/PINT_NSS: TP26.1, U11.46 (PB9); also elsewhere on the board
/Debugger/PINT_SCK: TP25.1, U11.45 (PB8); also elsewhere on the board
/Emulator/EM_VIRTCAP_DAC: TP29.1, U11.16 (PA6); also elsewhere on the board
/Emulator/Emulator MCU/DBG_OUT_DIS_EN: R68.2, U11.3 (PC14); also elsewhere on the board
/Emulator/Emulator MCU/DBG_OUT_EN: R67.2, U11.2 (PC13); also elsewhere on the board
/Emulator/Emulator MCU/DBG_PSU_EN: R66.2, U11.28 (PD8); also elsewhere on the board
/Emulator/Emulator MCU/DBG_PSU_PG: U11.19 (PB1); also elsewhere on the board
/Emulator/Emulator MCU/DGB_OUT_ADC: U11.21 (PE8); also elsewhere on the board
/Emulator/Emulator MCU/DGB_PSU_DAC: U11.14 (PA4); also elsewhere on the board
/Emulator/Emulator MCU/EM_HIGH_CUR_ADC: U11.20 (PB2); also elsewhere on the board
/Emulator/Emulator MCU/EM_LOW_CUR_ADC: U11.26 (PB14); also elsewhere on the board
/Emulator/Emulator MCU/EM_LOW_RANGE_EN: R53.1, U11.13 (PA3); also elsewhere on the board
/Emulator/Emulator MCU/EM_OUT_ADC: U11.22 (PE9); also elsewhere on the board
/Emulator/Emulator MCU/EM_OUT_DIS_EN: R51.1, U11.11 (PA1); also elsewhere on the board
/Emulator/Emulator MCU/EM_OUT_EN: R50.1, U11.10 (PA0); also elsewhere on the board
/Emulator/Emulator MCU/EM_PSU_DAC: U11.15 (PA5); also elsewhere on the board
/Emulator/Emulator MCU/EM_PSU_EN: R52.1, U11.12 (PA2); also elsewhere on the board
/Emulator/Emulator MCU/EM_PSU_PG: U11.18 (PB0); also elsewhere on the board
/Emulator/Emulator MCU/PINT_INT2: U11.42 (PB6); also elsewhere on the board
/Emulator/Emulator MCU/SWDCLK: J6.4 (SWDCLK/TCK), U11.37 (PA14)
/Emulator/Emulator MCU/SWDIO: J6.2 (SWDIO/TMS), U11.34 (PA13)
/Emulator/Emulator MCU/TRACESWO: J6.6 (SWO/TDO), U11.39 (PB3)
/Emulator/Emulator MCU/USB+: R24.1, R39.2, U13.4 (I/O2)
/Emulator/Emulator MCU/USB-: R23.1, U13.6 (I/O1)
/Emulator/Emulator MCU/VRef_MCU: C42.2, C44.2, C69.1, U11.25 (VREFSD+), U18.5 (OUTS), U18.6 (OUTF)
/Emulator/Emulator MCU/VUSB_VAR_PSU: R29.2, R30.1
/Emulator/Emulator MCU/nRST: J6.10 (~RESET), R18.2, SW3.2, U11.7 (NRST)
GND: C24.2, C27.2, C42.1, C44.1, C45.2, C46.2, C47.2, C48.2, C49.2, C50.2, C51.2, C57.1, C62.2, C68.1, C69.2, J5.4 (ID), J5.5 (GND), J5.6 (Shield), J6.3 (GND), J6.5 (GND), J6.9 (GNDDetect), R30.2, R45.2, R50.2, R51.2, R52.2, R53.2, R66.1, R67.1, R68.1, SW3.1, U11.8 (VSSA), U11.23 (VSSSD), U11.47 (VSS), U13.2 (GND), U18.2 (GND), Y2.2, Y2.4; also elsewhere on the board
unnamed: D5.2 (A), J5.1 (VBUS), R29.1, TP13.1, U13.5 (VBUS)
unnamed: J5.3 (D+), U13.3 (I/O2)
unnamed: J5.2 (D-), U13.1 (I/O1)
unnamed: R45.1, U11.44 (BOOT0)
unnamed: R23.2, U11.32 (PA11)
unnamed: R24.2, U11.33 (PA12)
unnamed: C24.1, U11.5 (PF0), Y2.1
unnamed: C27.1, U11.6 (PF1), Y2.3
unnamed: C68.2, U18.1 (FILTER)
VDD: C45.1, C46.1, C47.1, C48.1, J6.1 (VTref), R18.1, R39.1, U11.1 (VBAT), U11.17 (VDD), U11.48 (VDD); also elsewhere on the board
VDDA: C49.1, C50.1, C51.1, C57.2, C62.1, U11.9 (VDDA), U11.24 (VDDSD), U18.3 (EN), U18.4 (IN); also elsewhere on the board

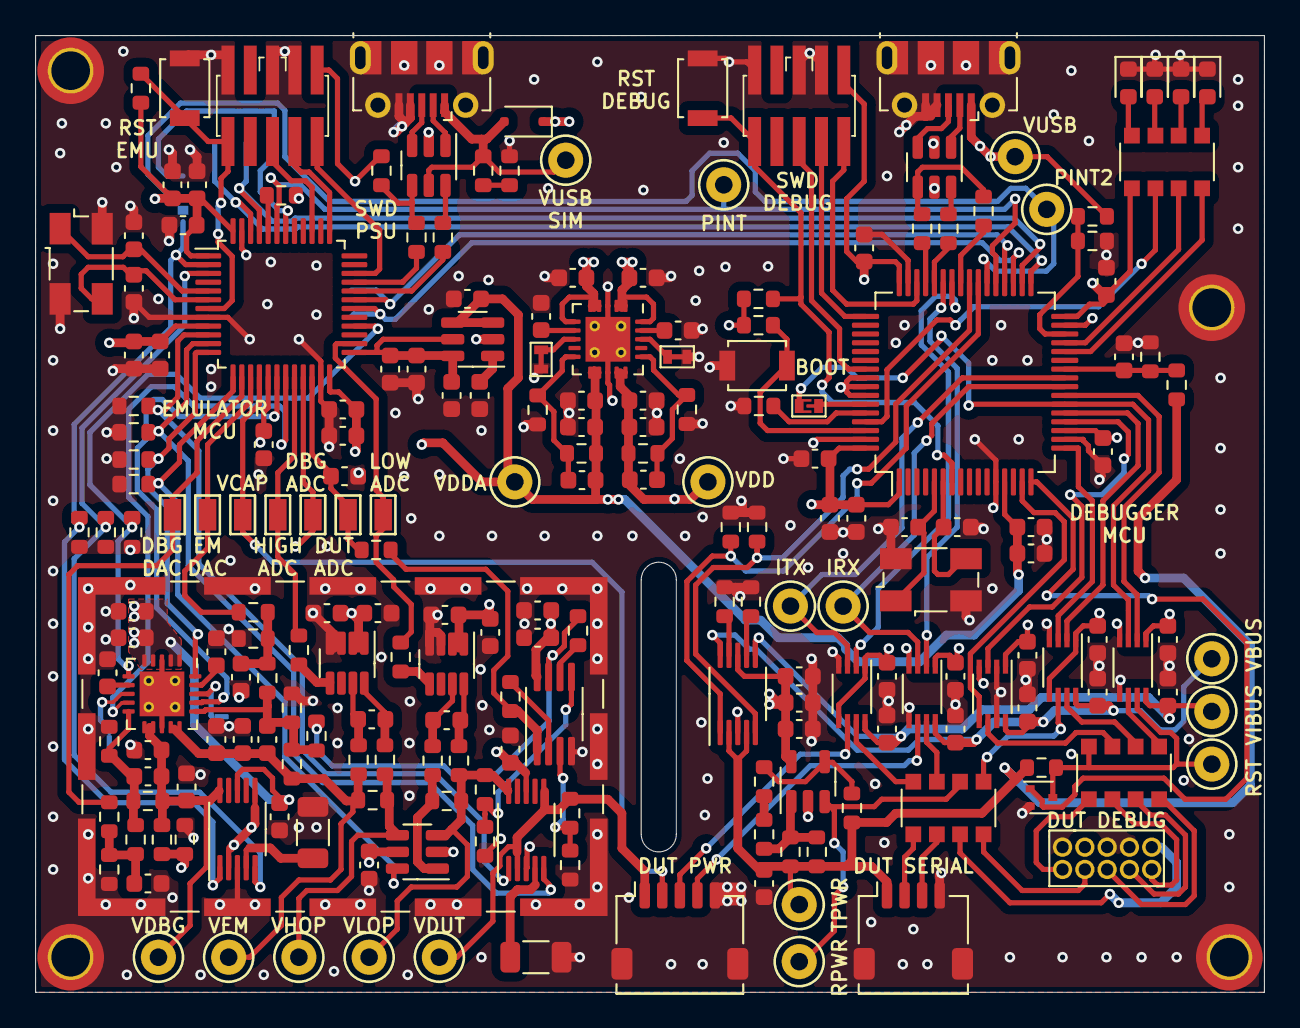
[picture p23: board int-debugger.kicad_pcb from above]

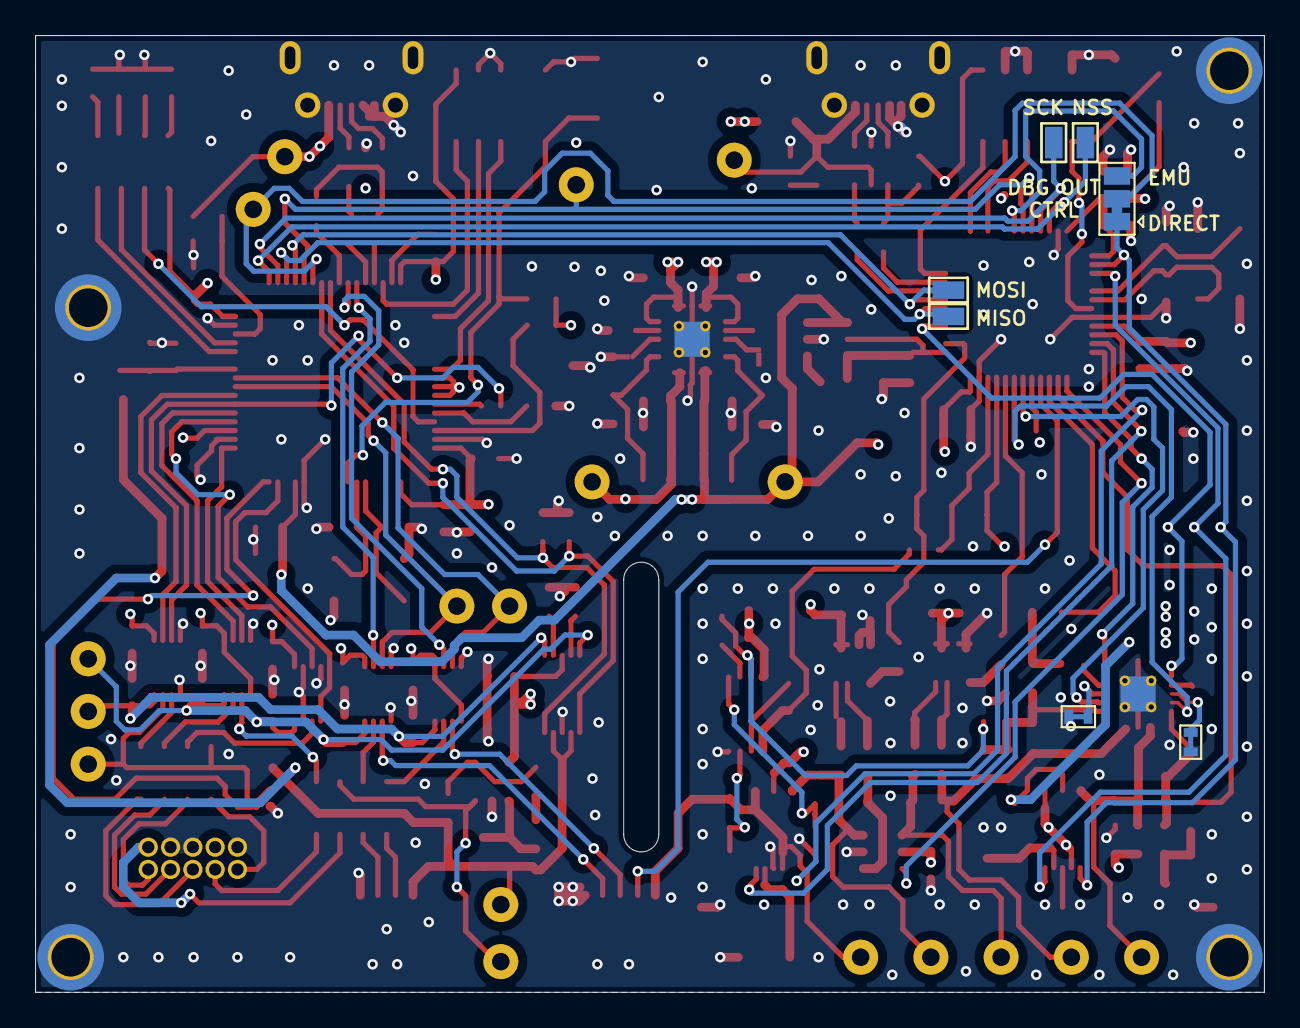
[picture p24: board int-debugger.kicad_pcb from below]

Board: 4 copper layers, 70.0 x 54.5 mm, 224 parts (7 on the bottom side), 142 nets.

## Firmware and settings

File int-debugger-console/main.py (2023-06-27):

#!/usr/bin/env python3
import re
import serial.tools.list_ports
from prompt_toolkit import PromptSession
from pydips.pyGDB import GDBController
import json
import argparse
from prompt_toolkit.history import FileHistory
from prompt_toolkit.auto_suggest import AutoSuggestFromHistory
from pydips.EnergyEmulator import EnergyEmulator

parser = argparse.ArgumentParser()
parser.add_argument('--version', action='store_true')
parser.add_argument('executable-file', nargs='?', default='')

parser.add_argument('--args')
parser.add_argument('--core')
parser.add_argument('--exec')
parser.add_argument('--pid')
parser.add_argument('--directory')
parser.add_argument('--se')
parser.add_argument('--symbols')
parser.add_argument('--readnow', action='store_true')
parser.add_argument('--readnever', action='store_true')
parser.add_argument('--write', action='store_true')

parser.add_argument('--command', '-x', )
parser.add_argument('--init-command', '-ix', action='store_const', const='FILE')
parser.add_argument('--eval-command', '-ex', action='store_const', const='COMMAND')
parser.add_argument('--init-eval-command', '-iex', action='store_const', const='COMMAND')
parser.add_argument('--nh', action='store_true')
parser.add_argument('--nx', action='store_true')

parser.add_argument('--fullname', action='store_true')
parser.add_argument('--interpreter')
parser.add_argument('--tty', action='store_const', const='TTY')
parser.add_argument('--w', action='store_true')
parser.add_argument('--nw', action='store_true')
parser.add_argument('--tui', action='store_true')
parser.add_argument('--dbx', action='store_true')
parser.add_argument('--quit', '--silent', '-q', action='store_true')

parser.add_argument('--batch', action='store_true')
parser.add_argument('--batch-silent', action='store_true')
parser.add_argument('--return-child-result', action='store_true')
parser.add_argument('--configuration', action='store_true')
parser.add_argument('-b', action='store_const', const='BAUDRATE')
parser.add_argument('-l', action='store_const', const='TIMEOUT')
parser.add_argument('--cd', action='store_const', const='DIR')
parser.add_argument('--data-directory', '-D', action='store_const', const='DIR')

args = parser.parse_args()

if args.version:
    print("GNU gdb (GNU Arm Embedded Intermittent Debugger 1-2022-q3) 1.0.0\n" +
          "Copyright (C) 2022 TU Delft.")
    exit(0)

if args.interpreter == 'mi2':
    session = None

else:
    #    Make sure there is a history file
    history = open('.dipscmdhistory', 'a')
    history.close()

    # Create session using prompt_toolkit
    session = PromptSession(history=FileHistory('.dipscmdhistory'))

# Used for autodetection of the serialport
DIPS_DEVICE_ID = 'Black Magic Probe  v0.0.1-dev-int-debug - Black Magic GDB Server'

# start the GDB Controller
gdb_c = GDBController(args)

# define emulator object
energy_emulator = EnergyEmulator()


def close_terminal():
    """
    Close terminal and kill all running processes
    :return:
    """
    exit(0)


def print_dips_help() -> None:
    """
    Print the dips help menu
    :return:
    """
    print_f("List of custom DIPS commands:\n", '~')
    print()
    print_f("break_mode -- Set supply to pause mode\n", '~')
    print_f("connect -- automatically detect the DIPS\n", '~')
    print_f("dips_gui -- Open the GUI of the power emulator\n", '~')
    print_f("dips_help -- Displays this help information in the cli\n", '~')
    print_f("dips_mem_check -- Start intermittency autotesting procedure for checkpoint correctness\n", '~')
    print_f("dips_peripheral_check -- Start intermittency autotesting procedure for peripheral correctness\n", '~')
    print_f("dips_forward_progress -- Start intermittency autotesting procedure for forward progress\n", '~')
    print_f("dips_energy_budget_finder -- Start intermittency autotesting procedure for finding the energy budget\n", '~')
    print_f("dips_profiler -- Start intermittency autotesting procedure for profiling\n", '~')
    print_f("energy_breakpoint -- Set an energy breakpoint on a line\n", '~')
    print_f("energy_guard -- Set an energysafe zone beteen two lines\n", '~')
    print_f("intermittent_count -- Return number of intermittences\n", '~')
    print_f("intermittent_mode -- Set debugger to intermittent or regular use\n", '~')
    gdb_c.done()


def argument_parser(cmd) -> None:
    """
    Format the command and run program accordingly
    :param cmd: command
    :return:
    """
    funct = cmd.split(" ")[0]
    #     # if funct[0].isdigit():
    #     #     funct = funct[1:]
    if funct == "dips_gui":
        pass
        # print("Not implemented, open DIPS GUI Manually")
    elif funct == "dips_help":
        print_dips_help()
    elif funct == "dips_mem_check":
        dips_memory_check(cmd.split(" ")[1:])
    elif funct == "dips_peripheral_check":
        dips_peripheral_check(cmd.split(" ")[1:])
    elif funct == "dips_forward_progress":
        dips_forward_progress_check(cmd.split(" ")[1:])
    elif funct == "dips_energy_budget_finder":
        dips_energy_budget_finder(energy_emulator, cmd.split(" ")[1:])
    elif funct == "dips_profiler":
        dips_profiler(energy_emulator, cmd.split(" ")[1:])
    elif funct == "intermittent_count":
        intermittent_count()
    elif funct == "intermittent_mode":
        intermittent_mode(cmd.split(" ")[1:])
    elif funct == "connect" or funct == "-target-select remote":
        dips_connect(cmd.split(" "))
    elif funct == "connect-emulator":
        energy_emulator.auto_connect()
    elif funct == "clear" or funct == "cls":
        clear_screen()
    elif funct == "energy_guard" or funct == "eg":
        gdb_c.set_energyguard(cmd.split(" ")[1:])
    elif funct == "1-gdb-version2-environment-cd":
        return
    elif funct == "delete_energy_guard" or funct == "d_eg":
        gdb_c.delete_energyguard(cmd.split(" ")[1:])
    elif funct == "energy_breakpoint" or funct == "eb" or funct == "energy_break":
        gdb_c.set_energybreakpoint(cmd.split(" ")[1:])
    elif funct == "delete_energy_breakpoint" or funct == "d_eb" or funct == "d_energy_break":
        gdb_c.delete_energybreakpoint(cmd.split(" ")[1:])
    elif funct == "quit":
        gdb_c.quit()
        close_terminal()
    elif funct == "dips_interrupt":
        gdb_c.add_interrupt_point(cmd.split(" ")[1])
    elif funct == "c" or funct[:4] == "cont":
        gdb_c.cont()
    elif funct[:2] == "17":
        dips_connect(["dips_connect"])
        return
    elif funct == "-target-select":
        dips_connect(["dips_connect"])
    # elif funct == '-interpreter-exec' and cmd.split(" ")[5] == 'console':
    #     return argument_parser(re.findall('"([^"]*)"', cmd)[0])
    elif funct == "wait_connect":
        dips_wait_connect(["dips_connect"])
    else:
        gdb_c.write(cmd)


def dips_memory_check(args):
    """
    Start dips memory check automated testing procedure
    :param args:
    :return:
    """
    if not gdb_c.is_connected():
        print_f("No device connected\n", '~')
        return

    print_f("Starting memory automated testing procedure....\n", '~')
    if len(args) != 2:
        print_f("Using checkpoint and restore functions from default configuration\n", '~')
        print_f("Add checkpoint and restore as arguments to change this\n", '~')
        with open('dips_testing.json') as json_file:
            data = json.load(json_file)
            gdb_c.test_mem_check(
                data['memcheck']['checkpoint_function'],
                data['memcheck']['restore_function']
            )
    else:
        gdb_c.test_mem_check(args[0], args[1])

def dips_forward_progress_check(args):
    """
    Start dips forward progress check automated testing procedure
    :param args:
    :return:
    """
    if not gdb_c.is_connected():
        print_f("No device connected\n", '~')
        return

    print_f("Starting memory automated testing procedure....\n", '~')
    if len(args) != 1:
        print_f("Using checkpoint from default configuration\n", '~')
        print_f("Add checkpoint as arguments to change this\n", '~')
        with open('dips_testing.json') as json_file:
            data = json.load(json_file)
            gdb_c.test_forward_progress(
                data['memcheck']['checkpoint_function'],
            )
    else:
        gdb_c.test_forward_progress(args[0])

def dips_peripheral_check(args):
    """
    Start dips peripheral check automated testing procedure
    :param args:
    :return:
    """
    if not gdb_c.is_connected():
        print_f("No device connected\n", '~')
        return

    print_f("Starting peripheral automated testing procedure....\n", '~')
    if len(args) != 2:
        print_f("Using checkpoint and restore functions from default configuration\n", '~')
        print_f("Add checkpoint and restore as arguments to change this\n", '~')
        with open('dips_testing.json') as json_file:
            data = json.load(json_file)
            gdb_c.test_peripheral(
                data['peripheral']['checkpoint_function'],
                data['peripheral']['restore_function']
            )
    else:
        gdb_c.test_peripheral(args[0], args[1])


def dips_energy_budget_finder(energy_emulator, args):
    """
    Start energy budget finder automated testing procedure
    :param args:
    :return:
    """
    if not gdb_c.is_connected():
        print_f("No device connected\n", '~')
        return

    print_f("Starting forward progress automated testing procedure....\n", '~')
    if len(args) != 2:
        print_f("Using checkpoint and restore functions from default configuration\n", '~')
        print_f("Add checkpoint and restore as arguments to change this\n", '~')
        with open('dips_testing.json') as json_file:
            data = json.load(json_file)
            gdb_c.find_energy_budget(
                energy_emulator,
                data['forwardprogress']['checkpoint_function'],
                data['forwardprogress']['restore_function'],
            )
    else:
        gdb_c.find_energy_budget(energy_emulator, args[0], args[1])

def dips_profiler(energy_emulator, args):
    """
    Start energy budget finder automated testing procedure
    :param args:
    :return:
    """
    if not gdb_c.is_connected():
        print_f("No device connected\n", '~')
        return

    print_f("Starting forward progress automated testing procedure....\n", '~')
    if len(args) != 2:
        print_f("Using checkpoint and restore functions from default configuration\n", '~')
        print_f("Add checkpoint and restore as arguments to change this\n", '~')
        with open('dips_testing.json') as json_file:
            data = json.load(json_file)
            gdb_c.profiler(
                energy_emulator,
                data['profiler']['indicate_end_function'],
                data['profiler']['possible_reboot_function'],
            )
    else:
        gdb_c.profiler(energy_emulator, args[0], args[1])

def intermittent_count():
    """
    Return number of intermittences
    :return: amount of intermittences
    """
    gdb_c.write('mon int_count')


def intermittent_mode(args):
    """
    Enable intermittent mode on the device
    :param args:
    :return:
    """
    if len(args) > 0:
        if args[0] == "true":
            gdb_c.write('mon int enable', raise_error_on_timeout=False)
        elif args[0] == "false":
            gdb_c.write('mon int disable', raise_error_on_timeout=False)
        else:
            print_f("Unknown command\n", '~')
    else:
        gdb_c.write('mon int', raise_error_on_timeout=False)


def dips_connect(args: []) -> None:
    """
    Autoconnect GDB using the known device name
    :param args:
    :return:
    """
    if len(args) == 1:
        port = return_serialport()
    else:
        port = args[1]
    if port is None:
        print_f("No device found with autoconnect", pref='^error,msg=')
        return

    print_f(f"found port: {port}", '~')
    gdb_c.connect(port)

def dips_wait_connect(args: []) -> None:
    
    if len(args) == 1:
        port = return_serialport()
    else:
        port = args[1]
    if port is None:
        print_f("No device found with autoconnect", pref='^error,msg=')
        return

    print_f(f"found port: {port}, only connects when DUT triggers UART RX pin", '~')
    
    gdb_c.wait_connect(port)


def return_serialport():
    """
    Get Blackmagic serialport
    :return: Serialport | None
    """
    ports = list(serial.tools.list_ports.comports())
    for p in ports:
        if p.description == DIPS_DEVICE_ID:
            return p.name

    return None


def clear_screen():
    """
    Clear the terminal
    """
    if not args.interpreter == 'mi2':
        session.output.erase_screen()


def print_f(output, pref=None, skip_on_term=False):
    if args.interpreter != 'mi2' and not skip_on_term:
        print(output)
    else:
        if not pref:
            print(repr(output)[1:-1])
        else:
            print(repr(f'{pref}"{output}"')[1:-1])


def main():
    """
    Start gdb, and terminal session, handle interrupts
    """
    gdb_c.start()
    # await _read_stdin_pipe()
    gdb_c.write('-gdb-set mi-async on', internal_step=True)
    # print(repr(f'~"dips program settings\n"'))

    gdb_c.get_response()

    while True:
        try:
            if args.interpreter == 'mi2':
                cmd = input()
                argument_parser(cmd)
                print("~" + cmd)

            else:
                cmd = session.prompt("(gdb) ",
                                     in_thread=True,
                                     auto_suggest=AutoSuggestFromHistory())

                argument_parser(cmd)
                while gdb_c.is_running():

                    gdb_c.get_response()
                    if not gdb_c.is_running():
                        break

        except KeyboardInterrupt:
            gdb_c.interrupt()
            return

        except BrokenPipeError:
            close_terminal()

        except EOFError as e:
            print(end="")


main()

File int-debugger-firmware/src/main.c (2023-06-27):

#include "general.h"
#include "gdb_if.h"
#include "gdb_main.h"
#include "target.h"
#include "exception.h"
#include "spi.h"

int main(void)
{
    platform_init();

    while (true) {
        volatile struct exception e;
        TRY_CATCH(e, EXCEPTION_ALL) {
            gdb_main();
        }
        if (e.type) {
            disable_supply();
            target_lost();
        }
    }

    /* Should never get here */
    return 0;
}
